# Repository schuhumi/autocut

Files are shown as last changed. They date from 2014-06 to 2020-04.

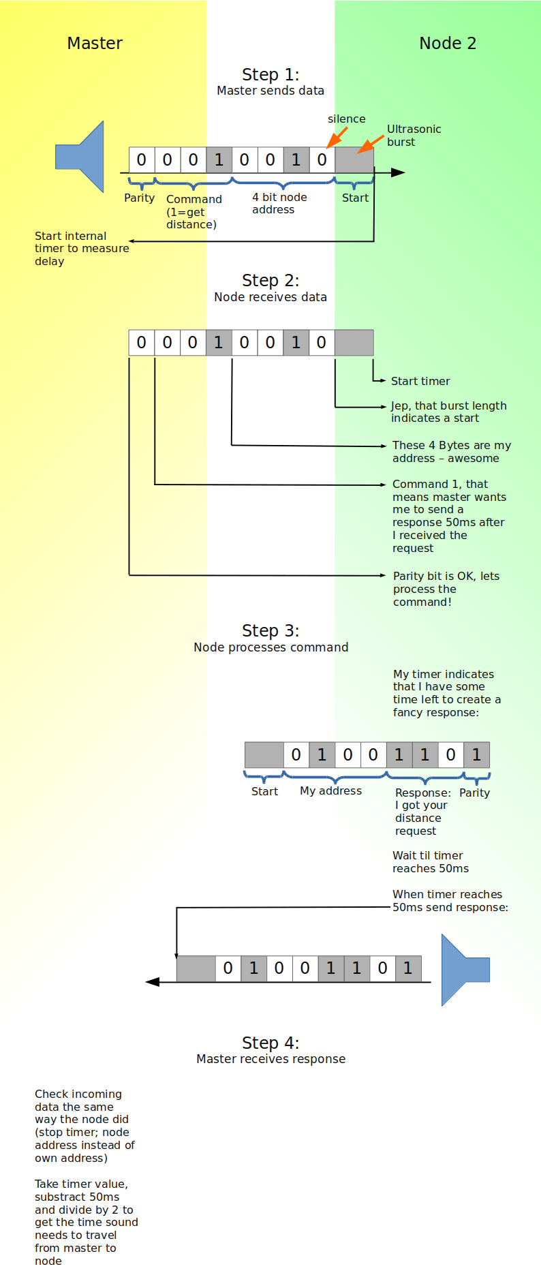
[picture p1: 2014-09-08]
Sketchboard/Ultrasonic Positioning System/Positioning System - the process.png

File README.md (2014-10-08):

autoCut
=======

autoCut is an automatic lawn mower robot. It features:
 - Four weel drive with kink steering
 - Motorized mowing height leveling
 - Two 85 watt mowing motors, each equipped with two very sharp blades, able to snap back on hard obstacles
 - On the fly interchangeable LiPo-battery with voltage monitoring
 - Wifi network connection for web interface which includes gamepad remote control
 - Raspberry Pi as its main computer and head of the microcontroller i2c-network

progress
========

What it can do already:
-----------------------
 - [drive system] works pretty much brilliant
 - [power supply] Measures individual cell voltages and rings an audible alarm in case of undervoltage or improper connected battery. Handles battery changes without losing power for the control system
 - [main module] Raspberry works quite well with ArchLinux ARM and provides a webinterface on the network. Will be replaced by Cubieboard 2 since RasPi has hardware I2C issues
 - [mowing module] Runs the mowing motors with a reasonably decent rpm regulation algorithm. Electrical mowing height adjustment through web interface is implemented.

What it can't do yet:
---------------------
 - [power supply] Measure the current as well as the total battery voltage
 - [general] No environmental sensoring for automatic movement yet, so manual control is needed

Things to improve:
------------------
 - [power supply] design a proper pcb (its on a prototyping board so far)
 - [mowing module] Change FETs for ones with lower heat dissipation and enhance the rpm regulation algorithm

Preserved for the future:
-------------------------
 - Build an automatic battery changing and charging station

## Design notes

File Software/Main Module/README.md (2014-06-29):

The software on the main module is separated into two parts.

Webserver
---------
The webserver hosts a html file and some javascript. This builds up the webinteface. Nginx is recommended as webserver, since its more lightweight than apache - which is a good thing on a weak emdedded platform.

Commandserver
-------------
This is a websocket-server written in Python3. It receives commands, processes them and sends information back. The webinterface uses the commandserver to control the robot.

RobotLibrary is a pile of functions for communicating with other modules (drive, mow, powersupply...) via I2C easily. The Commandserver uses them to process the commands.

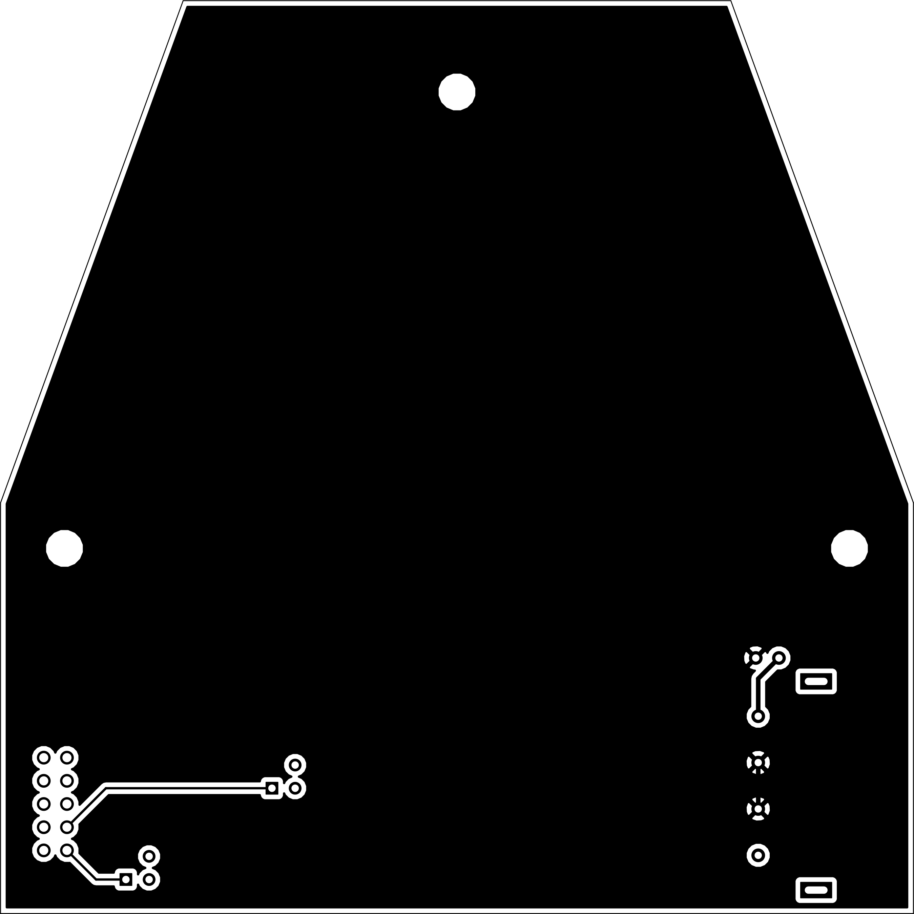
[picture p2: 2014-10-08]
Electronics/Main Module/MainModule-B_Cu.png

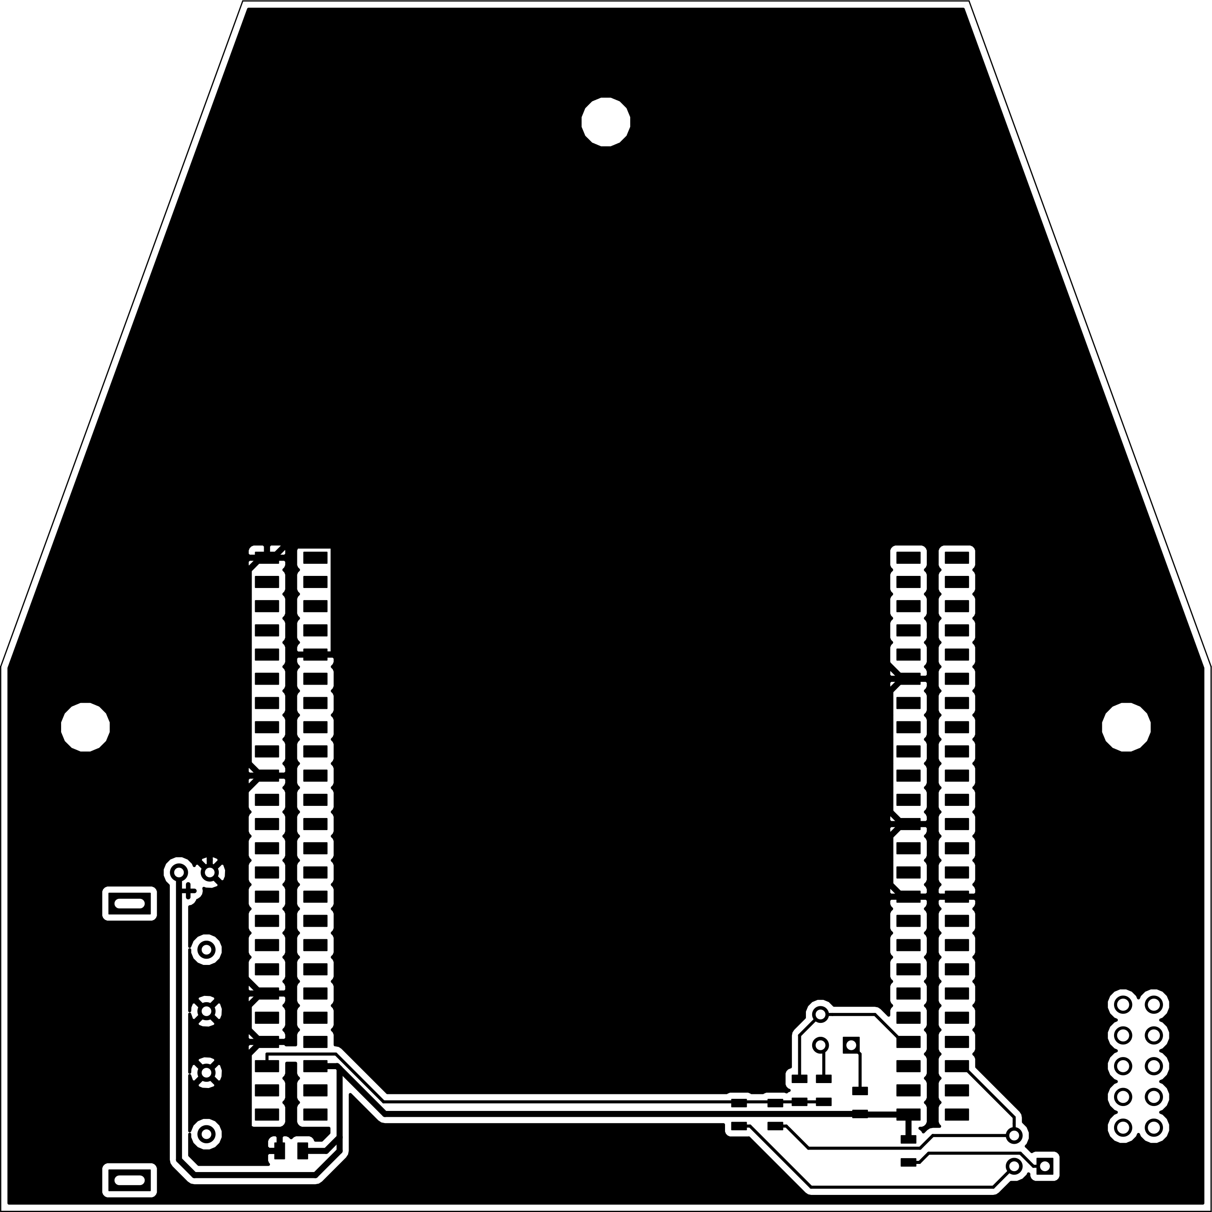
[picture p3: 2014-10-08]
Electronics/Main Module/MainModule-F_Cu.png

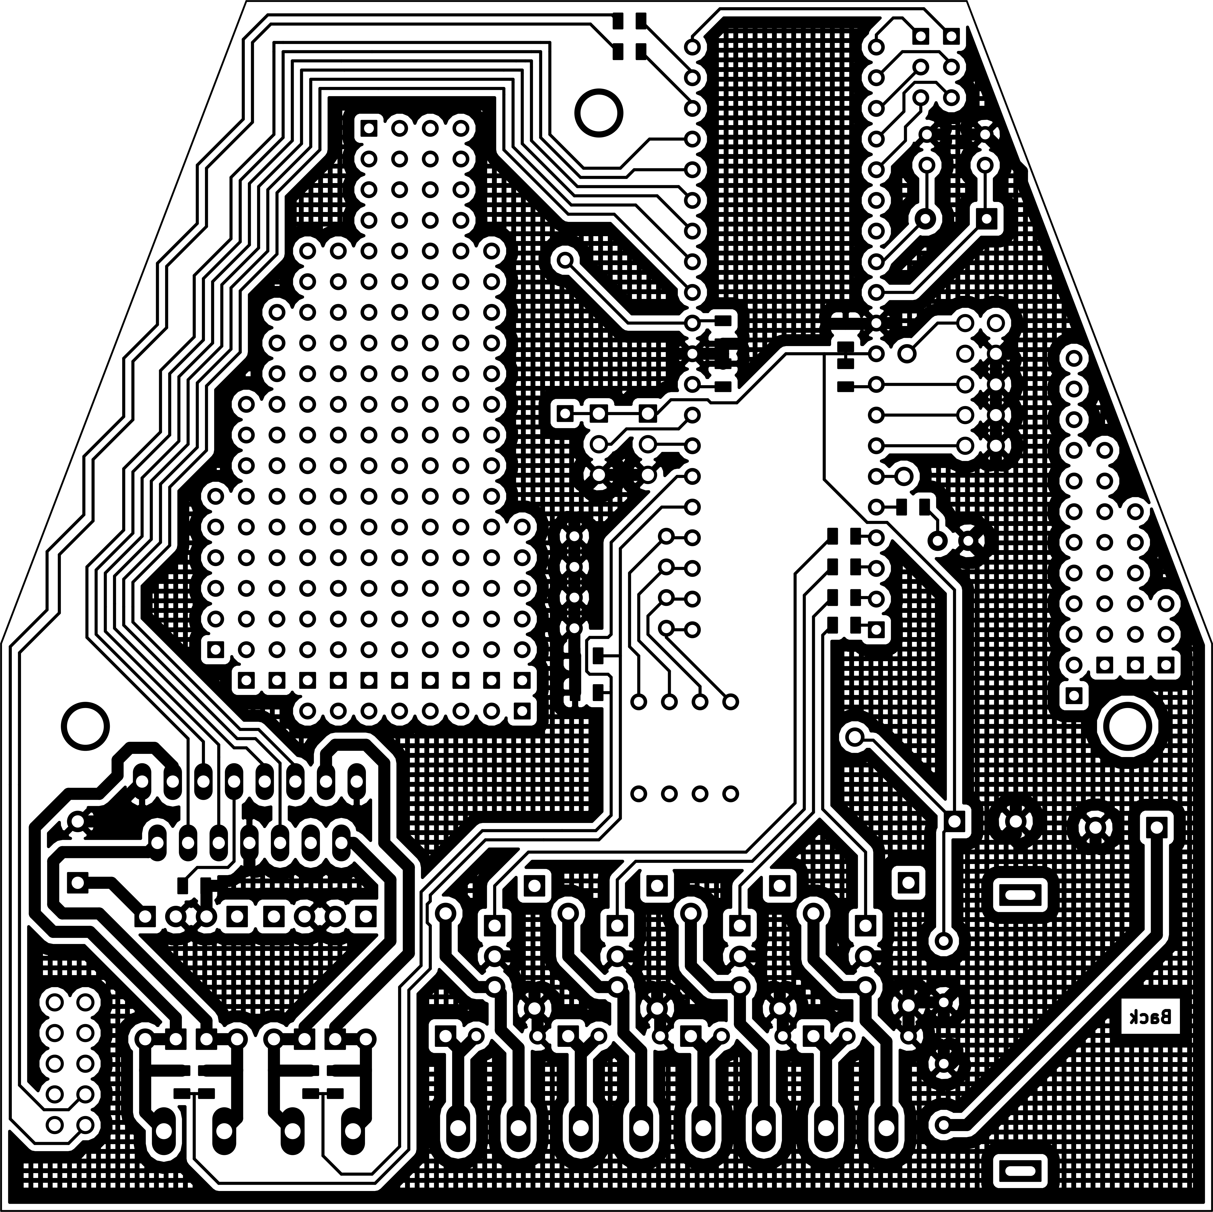
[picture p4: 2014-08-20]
Electronics/Mowing Module/plot/maehwerktreiber-B_Cu_grid.png

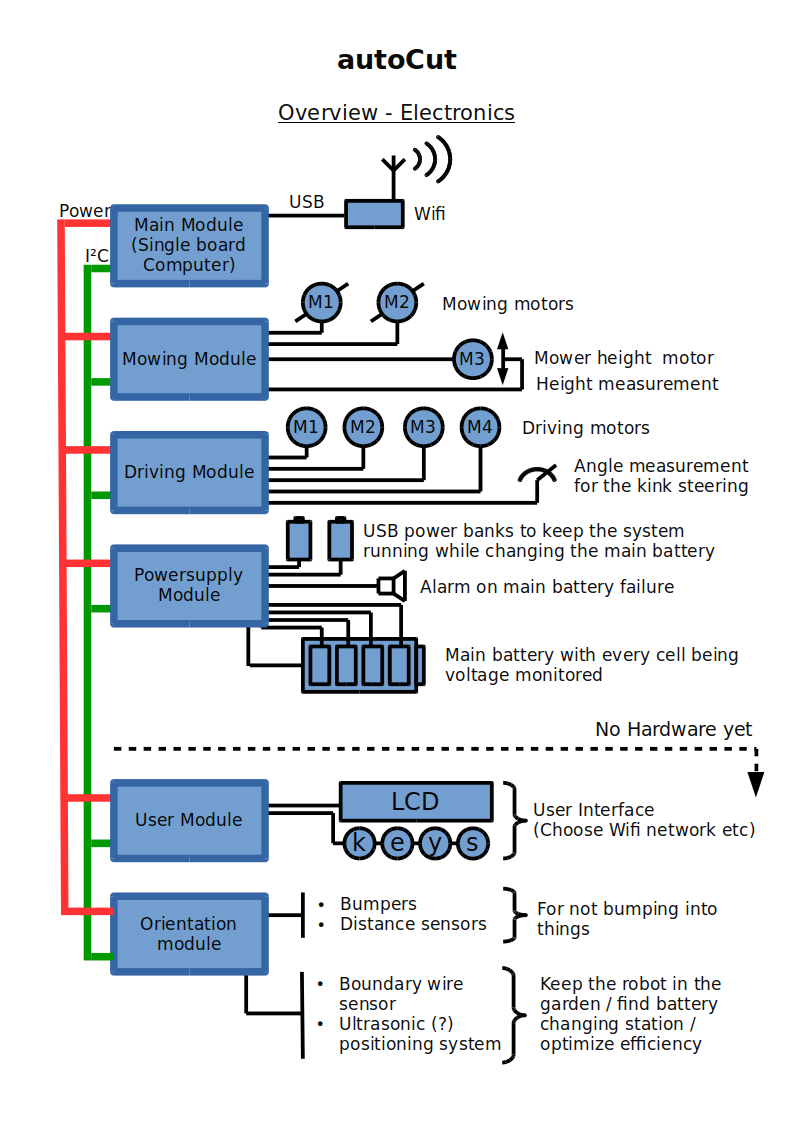
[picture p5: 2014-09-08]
Documentation/Visualisation/Overview - Electronics/Overview - Electronics.png

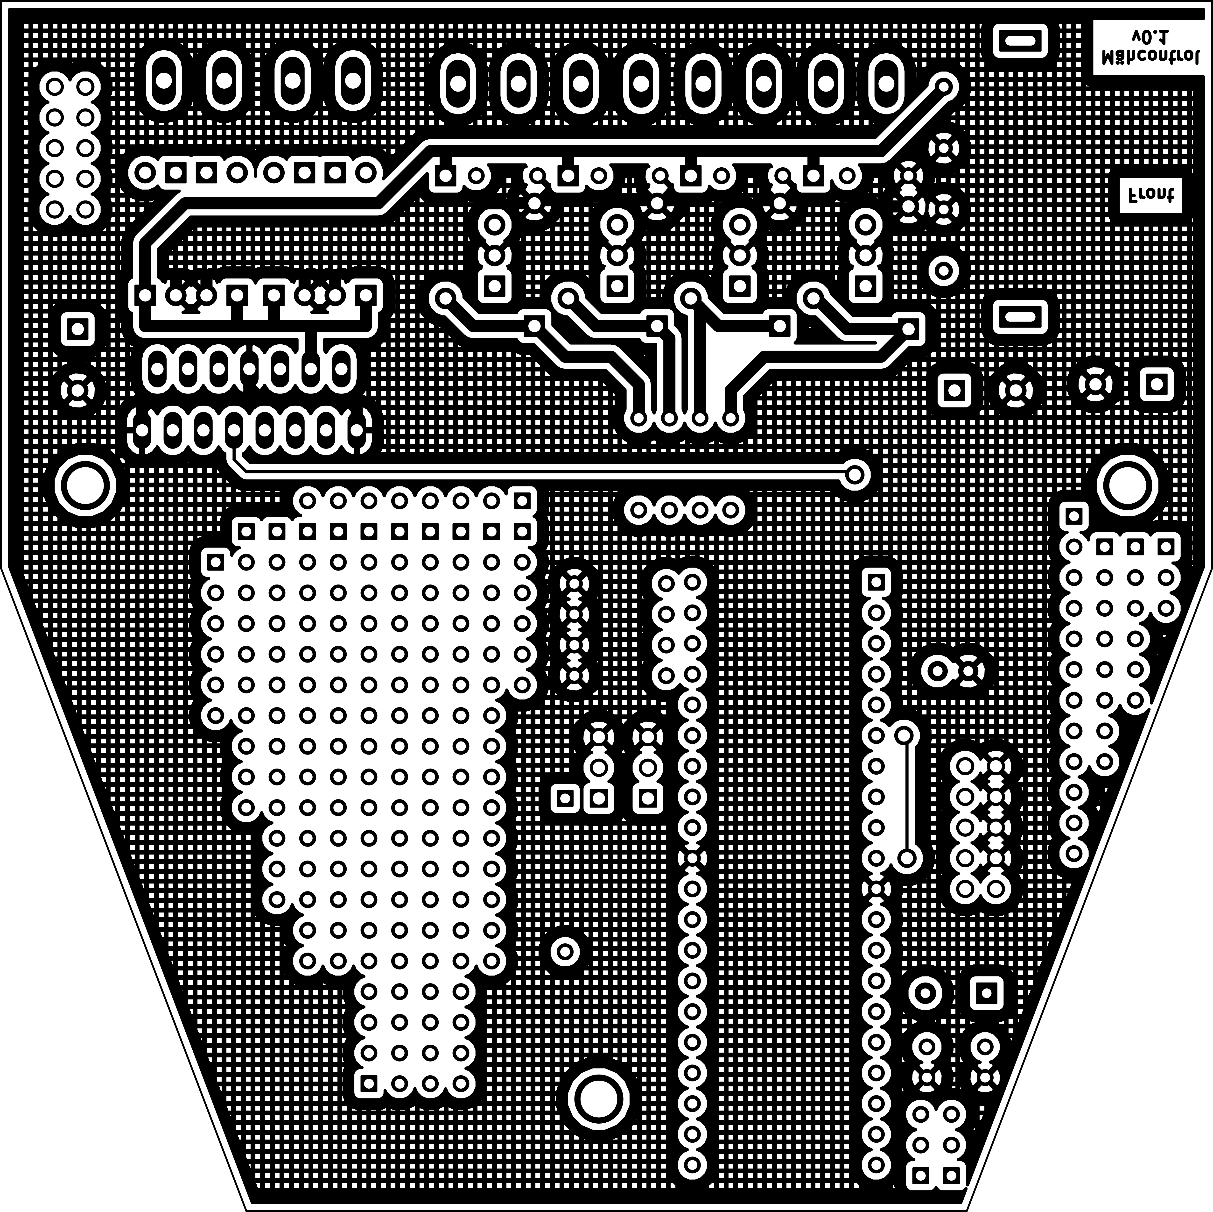
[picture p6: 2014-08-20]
Electronics/Mowing Module/plot/maehwerktreiber-F_Cu_grid.png

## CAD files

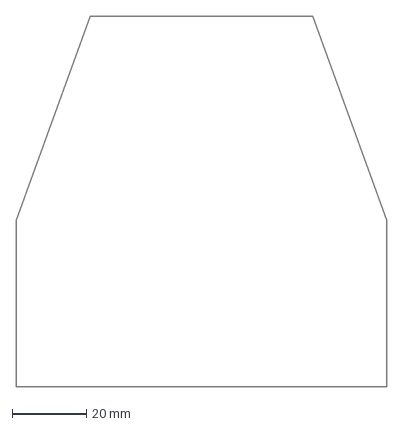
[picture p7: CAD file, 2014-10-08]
Electronics/Main Module/EdgeCuts.dxf
100.0 x 100.0 mm

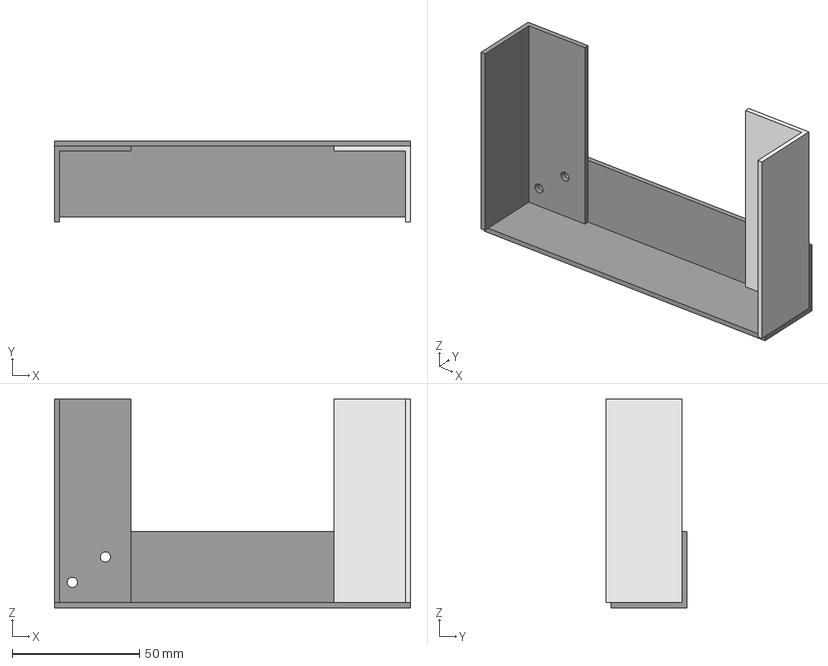
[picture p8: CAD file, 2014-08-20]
Mechanics/Chassis/Chassis.fcstd
140.0 x 32.0 x 82.0 mm

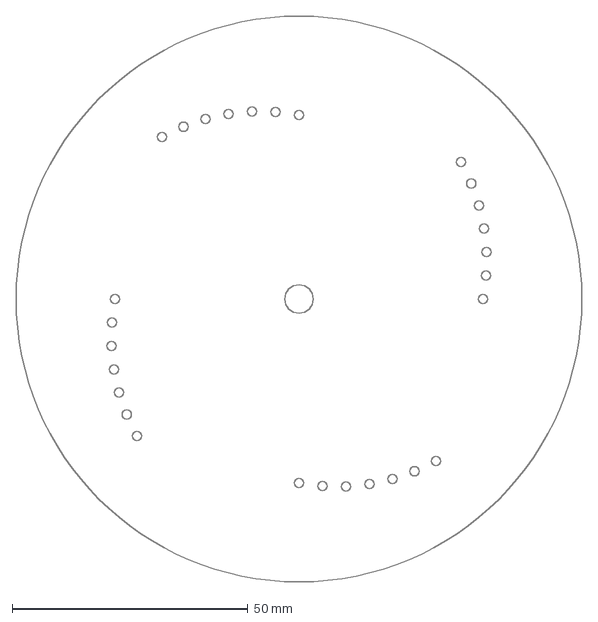
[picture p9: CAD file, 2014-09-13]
Mechanics/Mowing deck/mowing_plates.dxf
120.0 x 120.0 mm

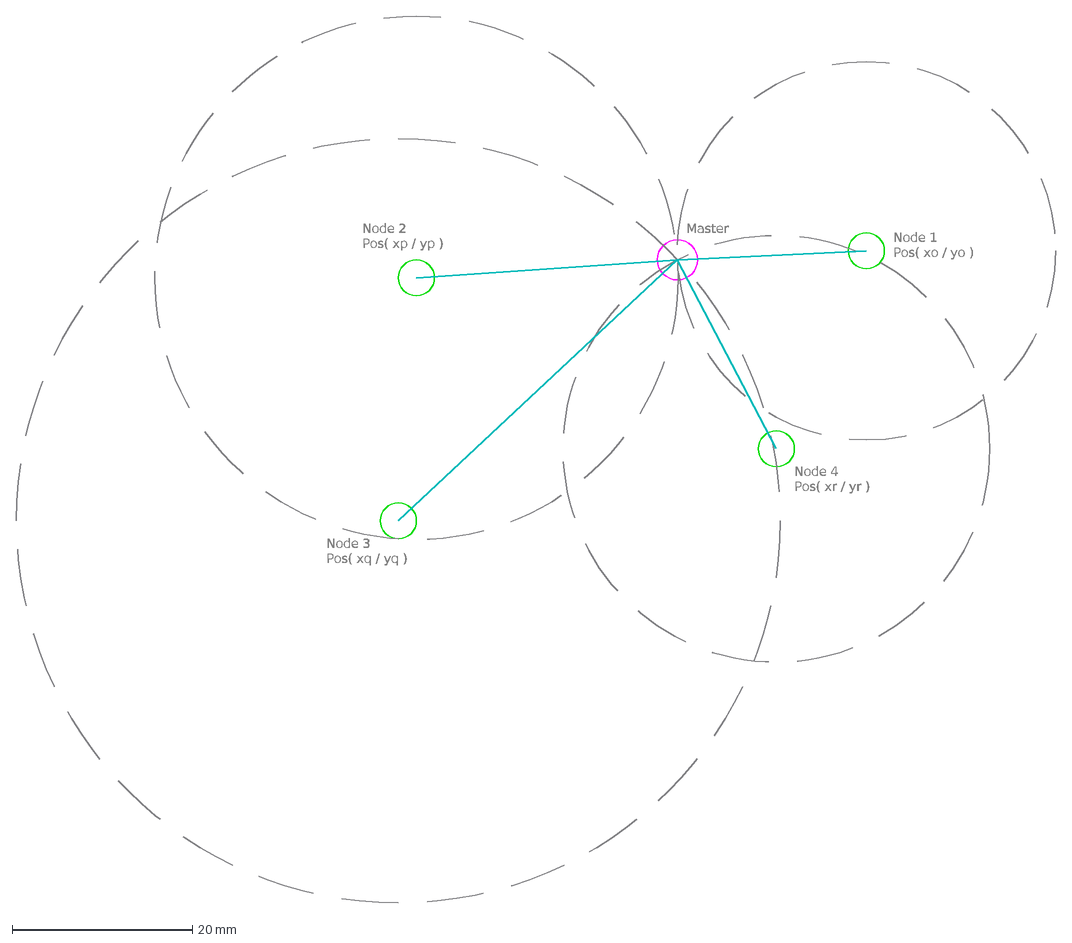
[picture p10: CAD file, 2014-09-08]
Sketchboard/Ultrasonic Positioning System/Positioning System.dxf
Node 2 Pos( xp / yp )
Node 1 Pos( xo / yo )
Node 3 Pos( xq / yq )
Node 4 Pos( xr / yr )
Master

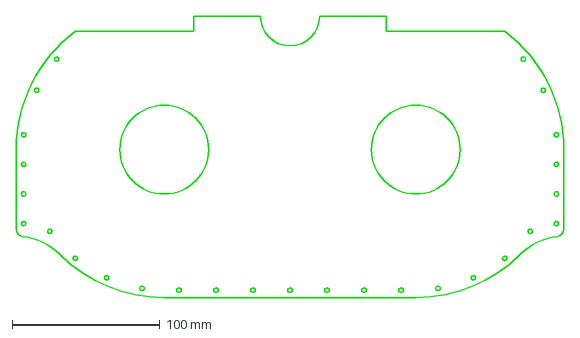
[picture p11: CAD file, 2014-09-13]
Mechanics/Mowing deck/mowing_system_abdeckung.dxf
370.0 x 190.0 mm

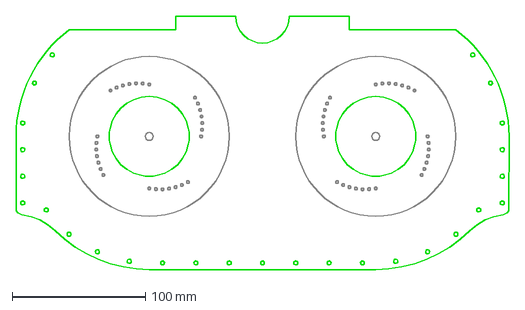
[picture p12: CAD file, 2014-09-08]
Mechanics/Mowing deck/mowing_system.dxf
370.0 x 190.0 mm

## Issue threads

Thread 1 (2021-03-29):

RE: I Just Saw this Idea/Seth

silver2row, 2021-03-29:
Hello,

https://www.open-electronics.org/a-robotic-lawn-mowers-powered-by-solar-energy-with-an-arduino-heart/

I know the above link has an arduino but there is a control circuit in that link further down the page for burying cables to handle runoff of the vehicle/autocut.

I thought this could help.

Seth

P.S. Anyway, I wish you luck w/ your endeavors. I started to follow this page and forked it too! So, I will attempt to perform this idea w/ my Beagleboard.org boards in the future. 3.3v logic is the idea w/ their boards...I will try it out!

Closed 2021-04-12.

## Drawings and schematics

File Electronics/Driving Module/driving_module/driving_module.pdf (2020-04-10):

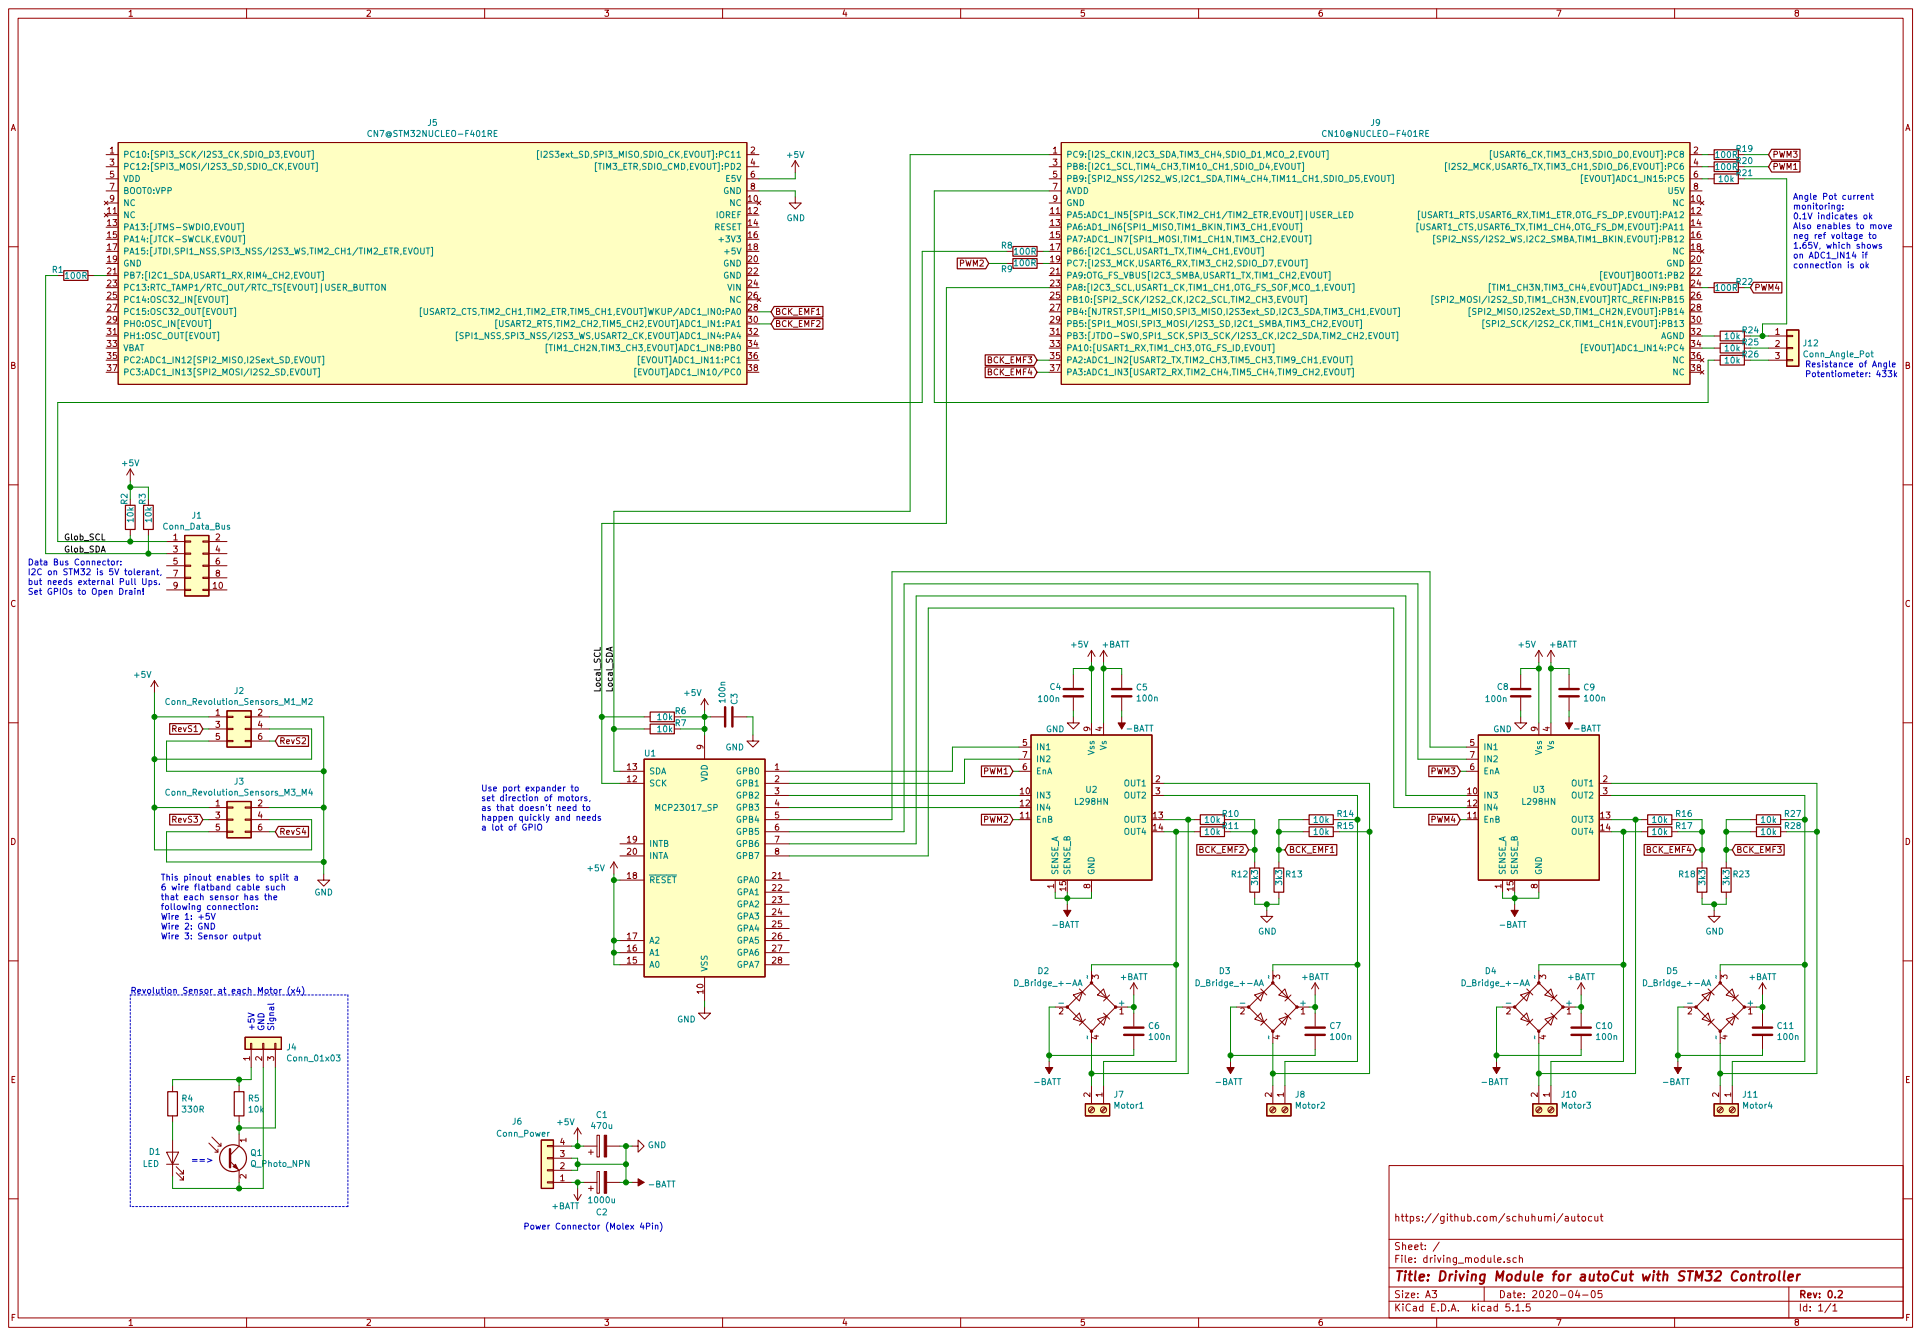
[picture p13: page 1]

Angle Pot current
monitoring: 0.1V indicates ok Also enables to move

neg ref voltage to
1.65V, which shows on ADC1_IN14 if connection is ok

Data Bus Connector:
I2C on STM32 is 5V tolerant, but needs external Pull Ups.

Set GPIOs to Open Drain!

following connection: Wire 1: +5V Wire 2: GND Wire 3: Sensor output +5V GND Signal ==>

Use port expander to
set direction of motors, as that doesn't need to

happen quickly and needs a lot of GPIO

This pinout enables to split a 6 wire flatband cable such

that each sensor has the

Revolution Sensor at each Motor (x4)

Id: 1/1 Title: Driving Module for autoCut with STM32 Controller

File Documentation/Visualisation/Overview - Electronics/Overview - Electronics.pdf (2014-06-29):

## autoCut

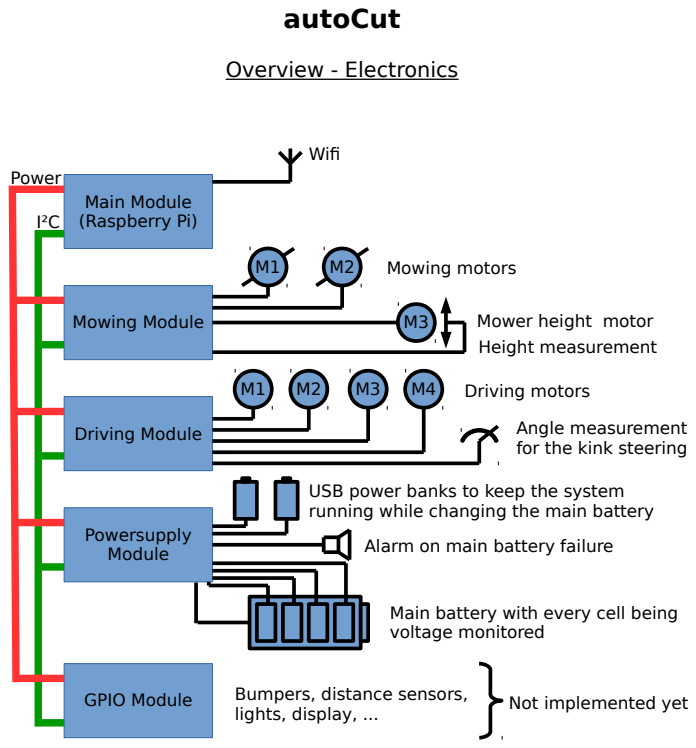
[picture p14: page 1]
Main Module (Raspberry Pi); Driving Module; Mowing Module; Powersupply Module; I²C; Power; Wif; Mowing motors; Mower height motor; Height measurement; Driving motors; Overview - Electronics; GPIO Module; Bumpers, distance sensors,; lights, display, ...; Not implemented yet

Angle measurement
for the kink steering

USB power banks to keep the system
running while changing the main battery
Alarm on main battery failure

Main battery with every cell being
voltage monitored

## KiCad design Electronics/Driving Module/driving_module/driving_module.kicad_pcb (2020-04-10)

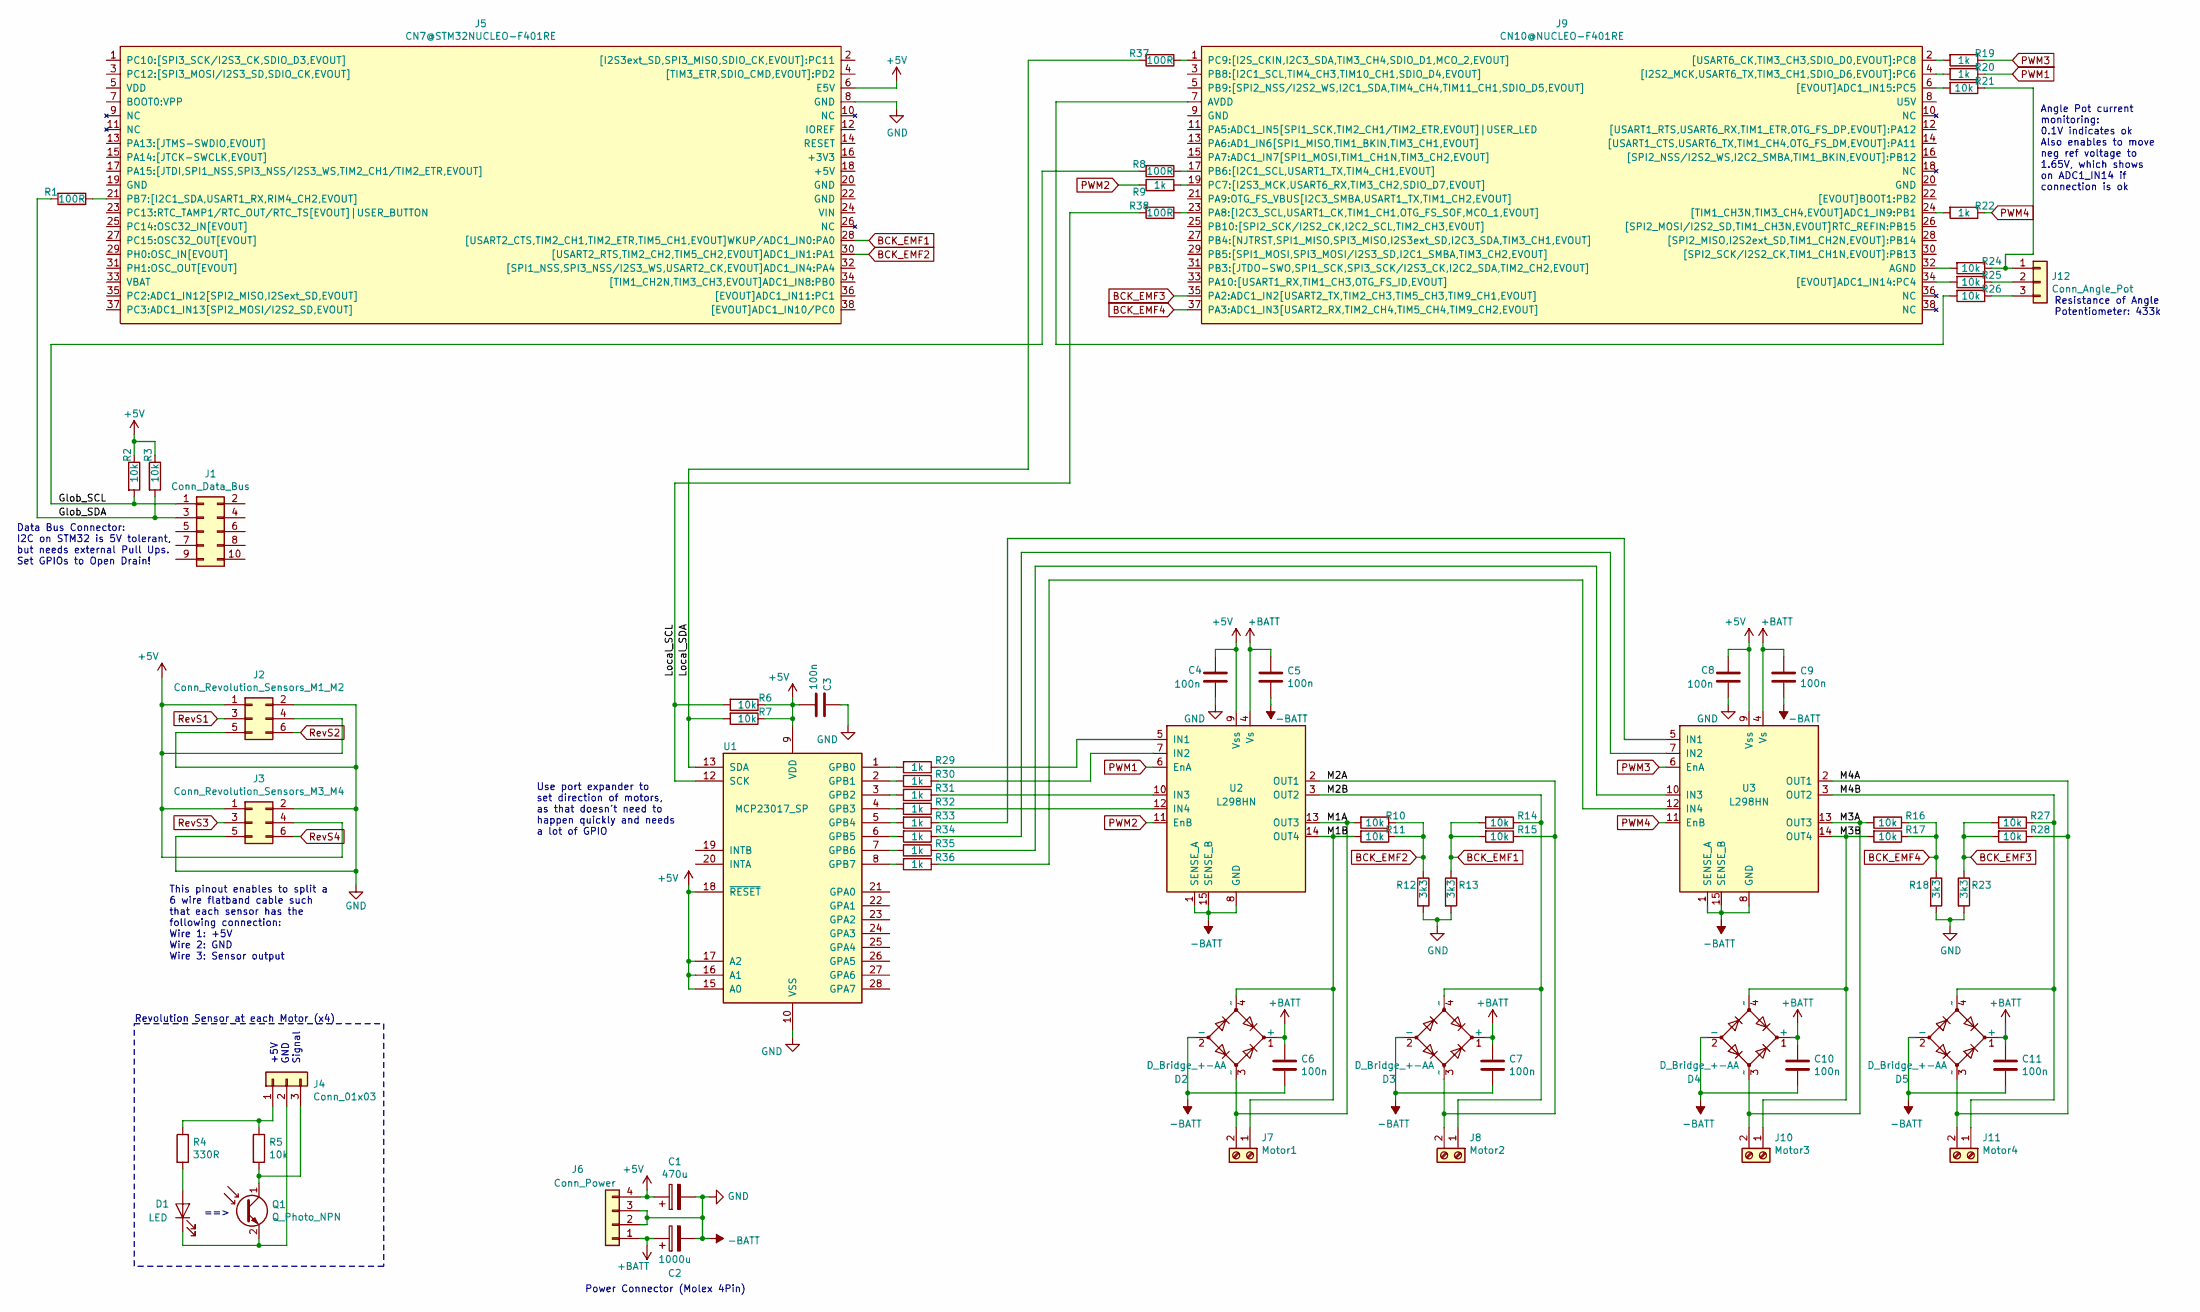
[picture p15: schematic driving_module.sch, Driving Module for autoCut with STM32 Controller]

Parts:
C1: 470u; CP_Radial_D8.0mm_P5.00mm
C2: 1000u; CP_Radial_D12.5mm_P5.00mm
C3, C4, C5, C6, C7, C8, C9, C10, C11: 100n; C_0805_2012Metric
D1: LED; LED_D3.0mm_Clear
D2, D3, D4, D5: D_Bridge_+-AA; Diode_Bridge_Diotec_SO-DIL-Slim
J1: Conn_Data_Bus; IDC-Header_2x05_P2.54mm_Vertical
J2: Conn_Revolution_Sensors_M1_M2; IDC-Header_2x03_P2.54mm_Vertical
J3: Conn_Revolution_Sensors_M3_M4; IDC-Header_2x03_P2.54mm_Vertical
J4: Conn_01x03; PinHeader_1x03_P2.54mm_Vertical
J5: CN7@STM32NUCLEO-F401RE; PinSocket_2x19_P2.54mm_Vertical
J6: Conn_Power; xess-MOLEX-8981-04P
J7: Motor1; TerminalBlock_bornier-2_P5.08mm
J8: Motor2; TerminalBlock_bornier-2_P5.08mm
J9: CN10@NUCLEO-F401RE; PinSocket_2x19_P2.54mm_Vertical
J10: Motor3; TerminalBlock_bornier-2_P5.08mm
J11: Motor4; TerminalBlock_bornier-2_P5.08mm
J12: Conn_Angle_Pot; PinHeader_1x03_P2.54mm_Vertical
Q1: Q_Photo_NPN; LED_D3.0mm_Clear
R1, R8, R37, R38: 100R; R_0805_2012Metric
R2, R3, R5, R6, R7, R10, R11, R14, R15, R16, R17, R21, R24, R25, R26, R27, R28: 10k; R_0805_2012Metric
R4: 330R; R_0805_2012Metric
R9, R19, R20, R22, R29, R30, R31, R32, R33, R34, R35, R36: 1k; R_0805_2012Metric
R12, R13, R18, R23: 3k3; R_Axial_DIN0207_L6.3mm_D2.5mm_P7.62mm_Horizontal
U1: MCP23017_SP; DIP-28_W7.62mm
U2, U3: L298HN; TO-220-15_P2.54x2.54mm_StaggerOdd_Lead4.58mm_Vertical_bent_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

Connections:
+5V: C1.1, C3.2, C4.1, C8.1, J2.1, J2.4, J3.1, J3.4, J5.6 (E5V), J6.4, R2.1, R3.1, R6.1, R7.1, U1.9 (VDD), U1.15 (A0), U1.16 (A1), U1.17 (A2), U1.18 (~RESET~), U2.9 (Vss), U3.9 (Vss)
+BATT: C2.1, C5.1, C6.1, C7.1, C9.1, C10.1, C11.1, D2.1 (+), D3.1 (+), D4.1 (+), D5.1 (+), J6.1, U2.4 (Vs), U3.4 (Vs)
-BATT: C1.2, C2.2, C3.1, C4.2, C5.2, C6.2, C7.2, C8.2, C9.2, C10.2, C11.2, D2.2 (-), D3.2 (-), D4.2 (-), D5.2 (-), J2.2, J2.5, J3.2, J3.5, J5.8 (GND), J6.2, J6.3, R12.2, R13.2, R18.2, R23.2, U1.10 (VSS), U2.1 (SENSE_A), U2.8 (GND), U2.15 (SENSE_B), U3.1 (SENSE_A), U3.8 (GND), U3.15 (SENSE_B)
/Glob_SCL: J1.1, R2.2, R8.2
/Glob_SDA: J1.3, R1.2, R3.2
/Local_SCL: R6.2, R38.2, U1.12 (SCK)
/Local_SDA: R7.2, R37.2, U1.13 (SDA)
/M1A: D2.3 (~~), J7.2, R10.2, U2.13 (OUT3)
/M1B: D2.4 (~~), J7.1, R11.2, U2.14 (OUT4)
/M2A: D3.3 (~~), J8.2, R15.1, U2.2 (OUT1)
/M2B: D3.4 (~~), J8.1, R14.1, U2.3 (OUT2)
/M3A: D4.3 (~~), J10.2, R16.2, U3.13 (OUT3)
/M3B: D4.4 (~~), J10.1, R17.2, U3.14 (OUT4)
/M4A: D5.3 (~~), J11.2, R28.1, U3.2 (OUT1)
/M4B: D5.4 (~~), J11.1, R27.1, U3.3 (OUT2)
BCK_EMF1: J5.28 ([USART2_CTS,TIM2_CH1,TIM2_ETR,TIM5_CH1,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), R13.1, R14.2, R15.2
BCK_EMF2: J5.30 ([USART2_RTS,TIM2_CH2,TIM5_CH2,EVOUT]ADC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), R10.1, R11.1, R12.1
BCK_EMF3: J9.35 (PA2:ADC1_IN2[USART2_TX,TIM2_CH3,TIM5_CH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), R23.1, R27.2, R28.2
BCK_EMF4: J9.37 (PA3:ADC1_IN3[USART2_RX,TIM2_CH4,TIM5_CH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), R16.1, R17.1, R18.1
unnamed: D1.1 (K), J4.2, Q1.2 (E)
unnamed: D1.2 (A), R4.2
unnamed: J4.1, R4.1, R5.1
unnamed: J4.3, Q1.1 (C), R5.2
unnamed: J5.21 (PB7:[I2C1_SDA,USART1_RX,RIM4_CH2,EVOUT]), R1.1
unnamed: J9.1 (PC9:[I2S_CKIN,I2C3_SDA,TIM3_CH4,SDIO_D1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), R37.1
unnamed: J9.2 ([USART6_CK,TIM3_CH3,SDIO_D0,EVOUT]:PC8), R19.2
unnamed: J9.4 ([I2S2_MCK,USART6_TX,TIM3_CH1,SDIO_D6,EV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), R20.2
unnamed: J9.6 ([EVOUT]ADC1_IN15:PC5), R21.2
unnamed: J9.7 (AVDD), R26.2
unnamed: J9.17 (PB6:[I2C1_SCL,USART1_TX,TIM4_CH1,EVOUT]), R8.1
unnamed: J9.19 (PC7:[I2S3_MCK,USART6_RX,TIM3_CH2,SDIO_D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), R9.2
unnamed: J9.23 (PA8:[I2C3_SCL,USART1_CK,TIM1_CH1,OTG_FS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), R38.1
unnamed: J9.24 ([TIM1_CH3N,TIM3_CH4,EVOUT]ADC1_IN9:PB1), R22.2
unnamed: J9.32 (AGND), R24.2
unnamed: J9.34 ([EVOUT]ADC1_IN14:PC4), R25.2
unnamed: J12.1, R21.1, R24.1
unnamed: J12.2, R25.1
unnamed: J12.3, R26.1
unnamed: R29.1, U2.5 (IN1)
unnamed: R29.2, U1.1 (GPB0)
unnamed: R30.1, U2.7 (IN2)
unnamed: R30.2, U1.2 (GPB1)
unnamed: R31.1, U2.10 (IN3)
unnamed: R31.2, U1.3 (GPB2)
unnamed: R32.1, U2.12 (IN4)
unnamed: R32.2, U1.4 (GPB3)
unnamed: R33.1, U3.5 (IN1)
unnamed: R33.2, U1.5 (GPB4)
unnamed: R34.1, U3.7 (IN2)
unnamed: R34.2, U1.6 (GPB5)
unnamed: R35.1, U3.10 (IN3)
unnamed: R35.2, U1.7 (GPB6)
unnamed: R36.1, U3.12 (IN4)
unnamed: R36.2, U1.8 (GPB7)
PWM1: R20.1, U2.6 (EnA)
PWM2: R9.1, U2.11 (EnB)
PWM3: R19.1, U3.6 (EnA)
PWM4: R22.1, U3.11 (EnB)
RevS1: J2.3
RevS2: J2.6
RevS3: J3.3
RevS4: J3.6

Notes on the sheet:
Resistance of Angle Potentiometer: 433k
Angle Pot current monitoring: 0.1V indicates ok Also enables to move neg ref voltage to 1.65V, which shows on ADC1_IN14 if connection is ok
Data Bus Connector: I2C on STM32 is 5V tolerant, but needs external Pull Ups. Set GPIOs to Open Drain!
Use port expander to set direction of motors, as that doesn't need to happen quickly and needs a lot of GPIO
This pinout enables to split a 6 wire flatband cable such that each sensor has the following connection: Wire 1: +5V Wire 2: GND Wire 3: Sensor output
+5V GND Signal
==>
Revolution Sensor at each Motor (x4)
Power Connector (Molex 4Pin)

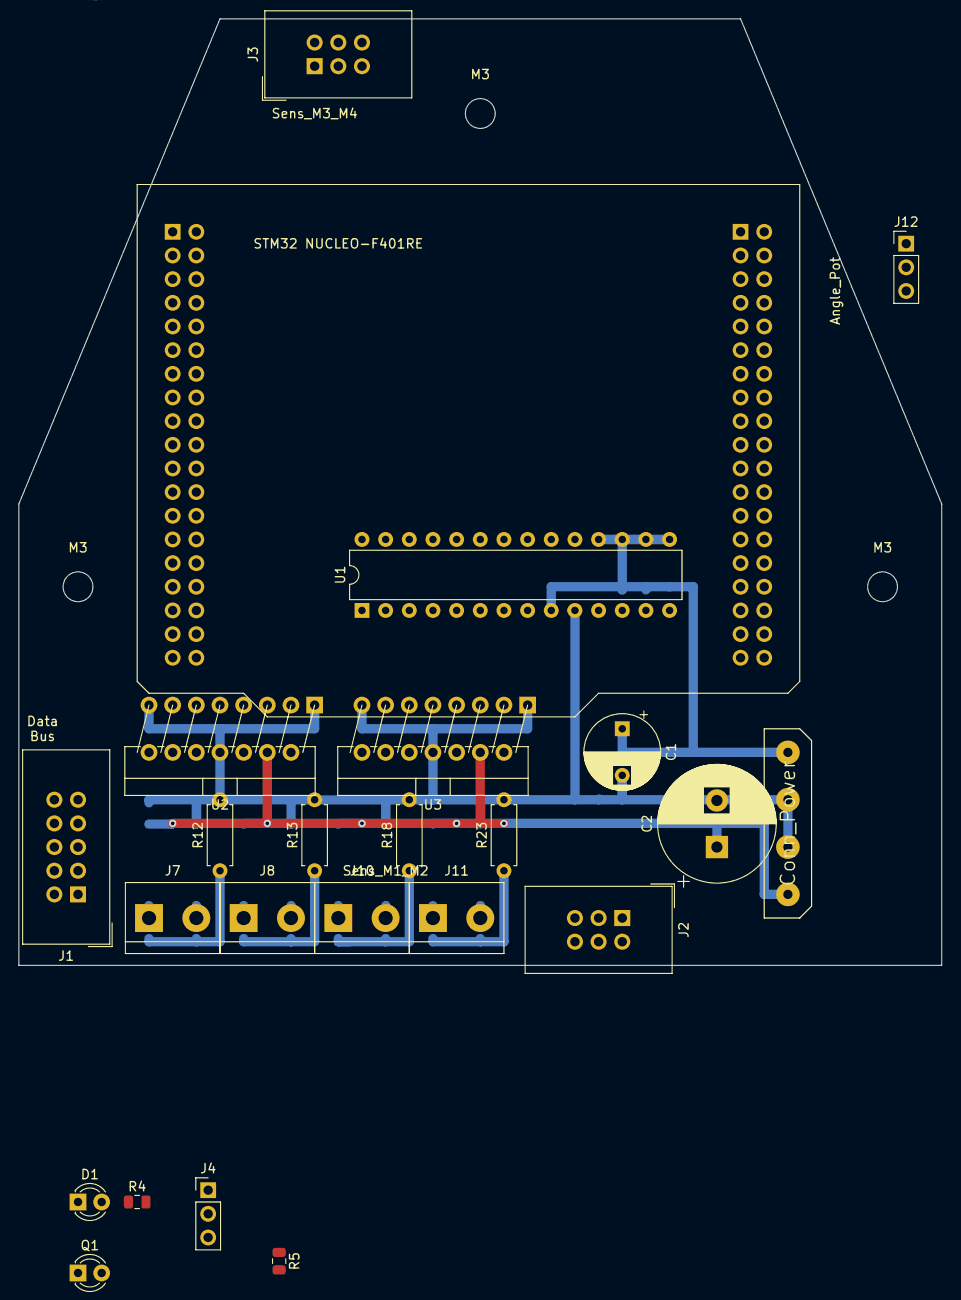
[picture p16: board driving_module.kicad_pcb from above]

Board: 4 copper layers, 99.1 x 101.6 mm, 73 parts (0 on the bottom side), 58 nets.

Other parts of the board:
M3, M3#2, M3#3: MountingHole_3.2mm_M3

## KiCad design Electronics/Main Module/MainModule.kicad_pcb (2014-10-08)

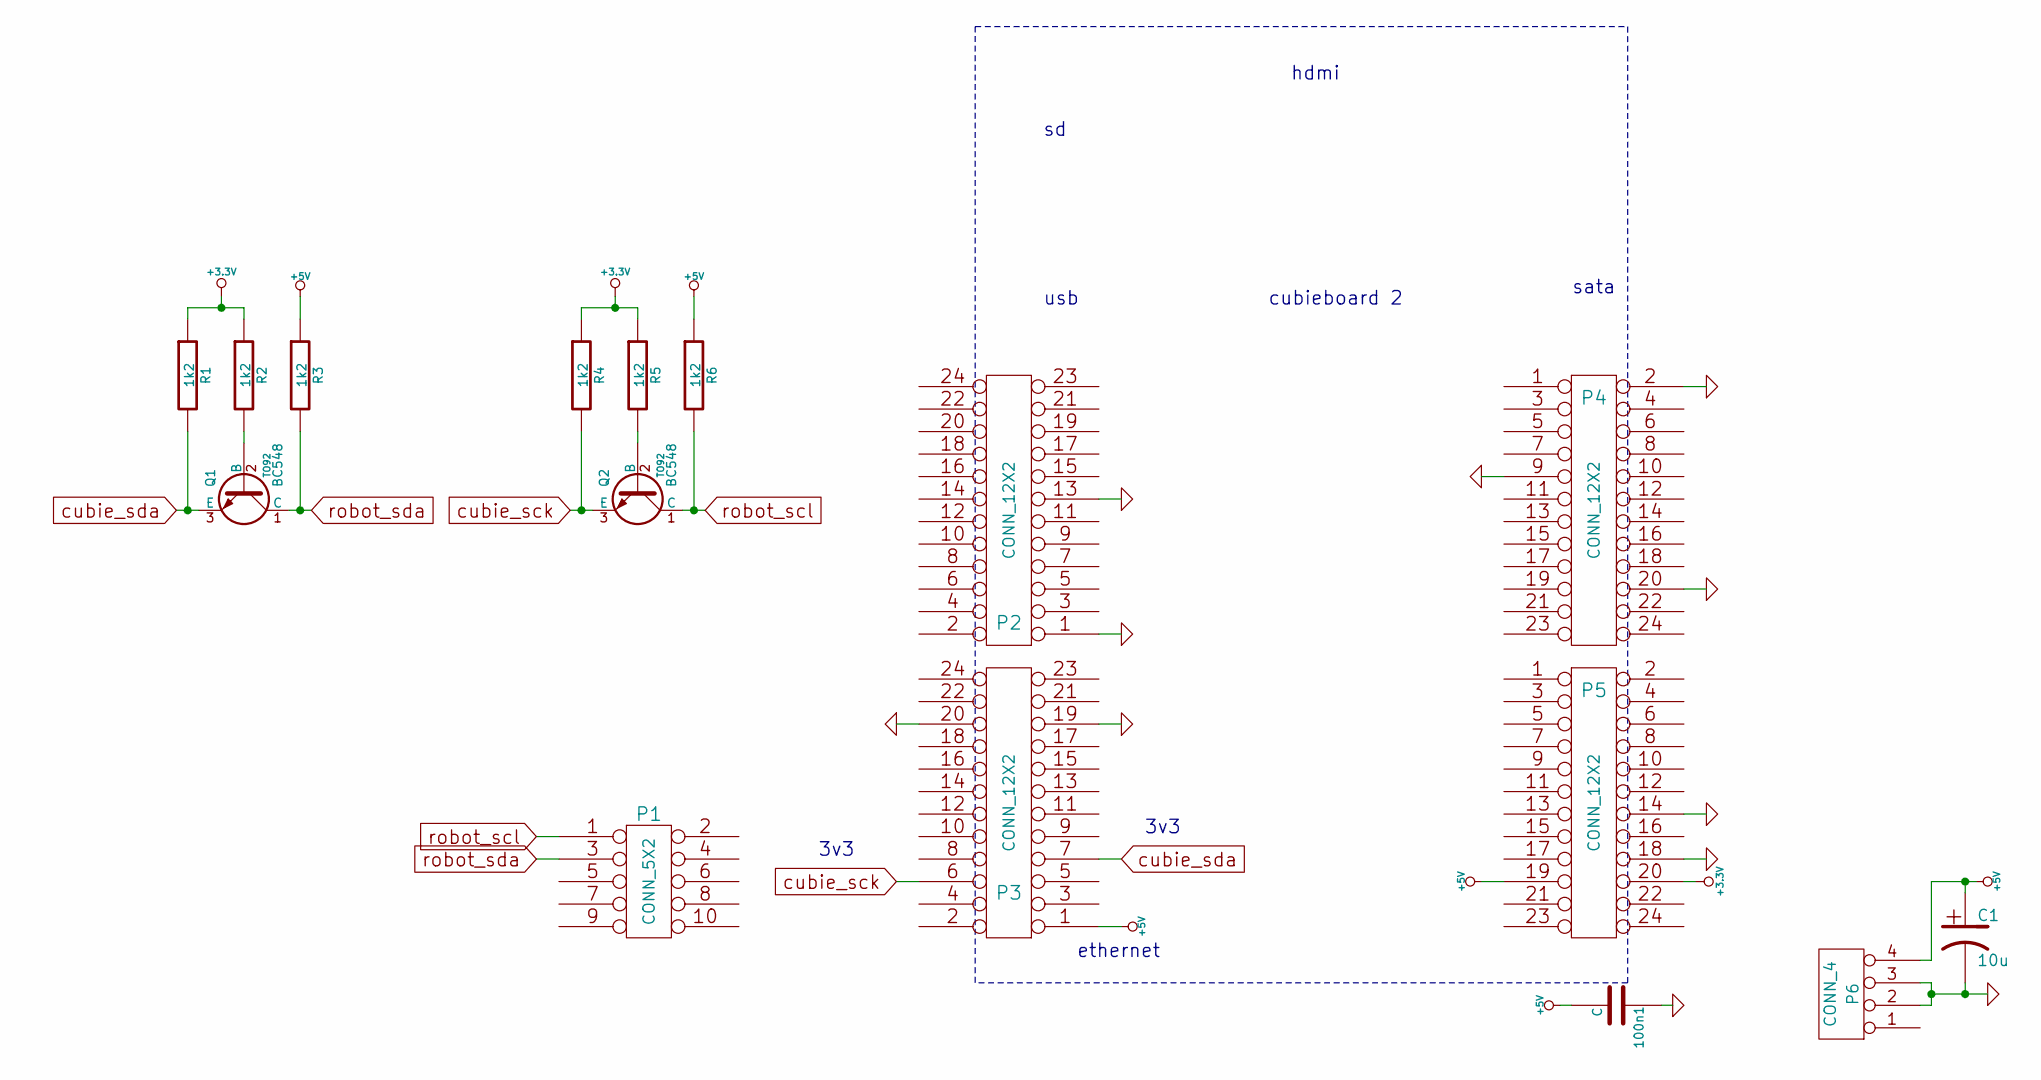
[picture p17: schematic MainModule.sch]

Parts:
100n1: C; SMD-0805
C1: 10u; Elko_vert_DM5_RM2-5
P1: CONN_5X2; VASCH5x2
P2, P3, P4, P5: CONN_12X2; SMD2mm_Header_12x2
P6: CONN_4; Molex
Q1, Q2: BC548; TO92
R1, R2, R3, R4, R5, R6: 1k2; R_0805

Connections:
+3.3V: P5.20, R1.1, R2.1, R4.1, R5.1
+5V: 100n1.2, C1.1, P3.1, P5.19, P6.4, R3.1, R6.1
GND: 100n1.1, C1.2, P2.1, P2.13, P3.19, P3.20, P4.2, P4.9, P4.20, P5.14, P5.18, P6.2, P6.3
unnamed: Q1.2 (B), R2.2
unnamed: Q2.2 (B), R5.2
cubie_sck: P3.6, Q2.3 (E), R4.2
cubie_sda: P3.7, Q1.3 (E), R1.2
robot_scl: P1.1, Q2.1 (C), R6.2
robot_sda: P1.3, Q1.1 (C), R3.2

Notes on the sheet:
cubieboard 2
sata
ethernet
usb
hdmi
3v3

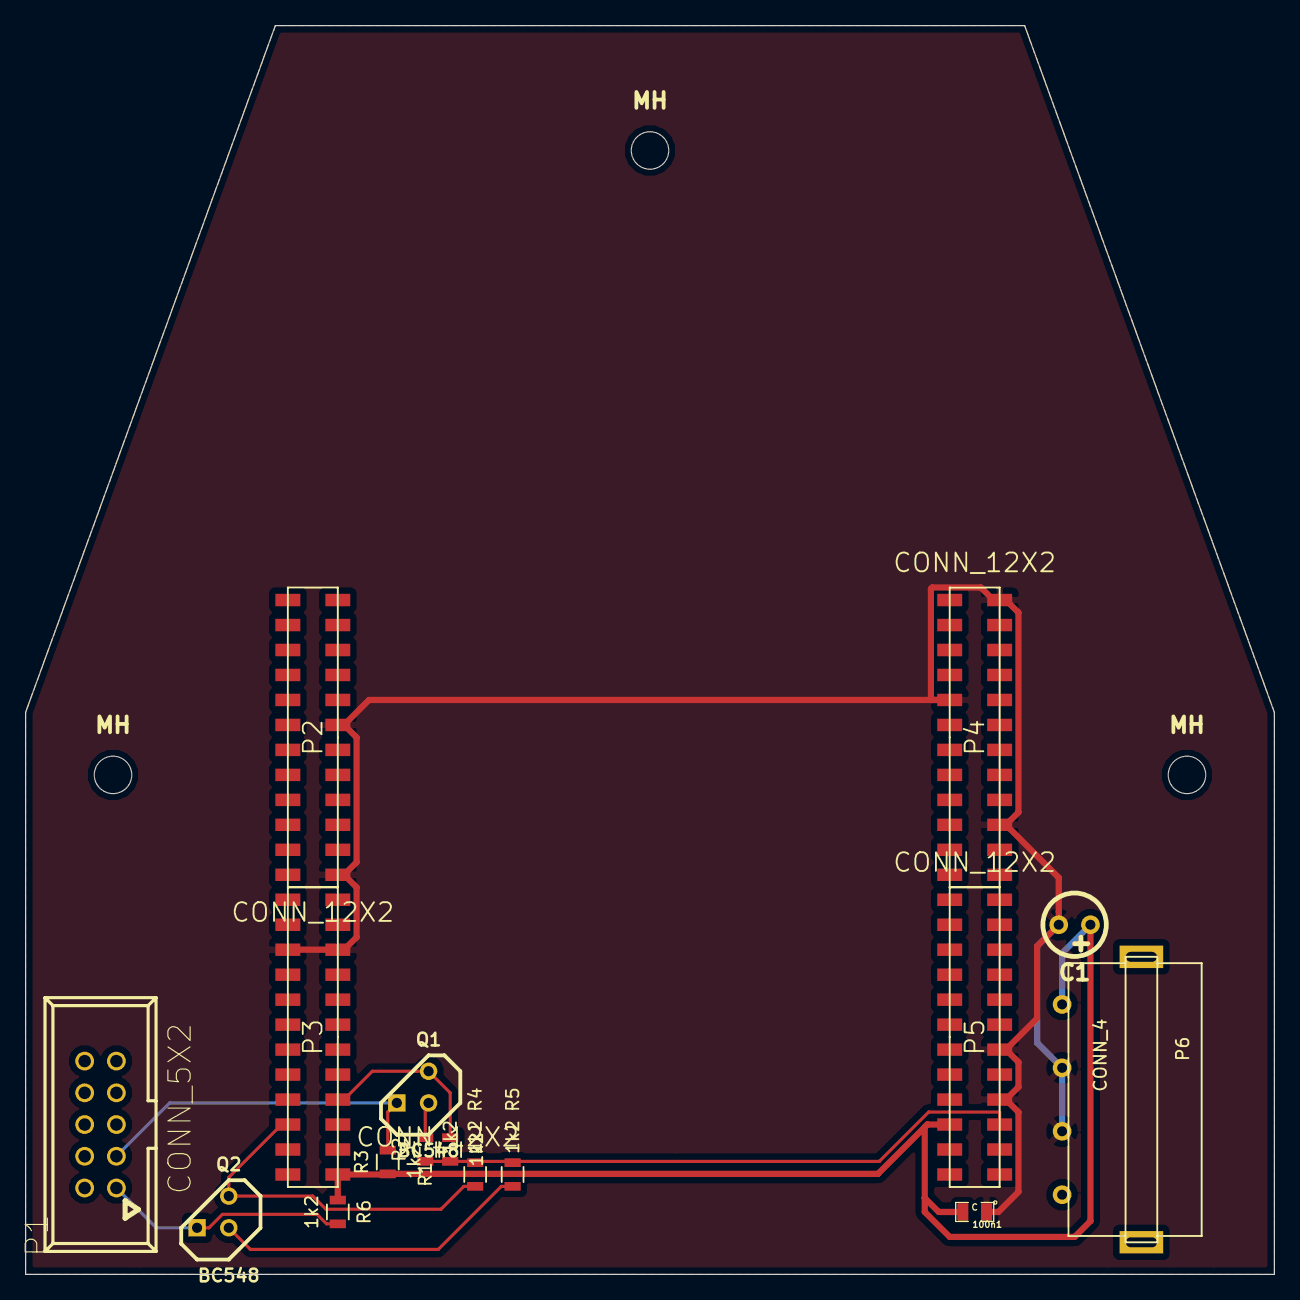
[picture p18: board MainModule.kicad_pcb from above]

Board: 2 copper layers, 100.0 x 100.0 mm, 19 parts (0 on the bottom side), 9 nets.

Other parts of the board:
MH: MountingHole_3mm_RevA_Date21Jun2010; MountingHole_3mm
MH#2, MH#3: MountingHole_3mm_RevA_Date21Jun2010; MountingHole_3mm

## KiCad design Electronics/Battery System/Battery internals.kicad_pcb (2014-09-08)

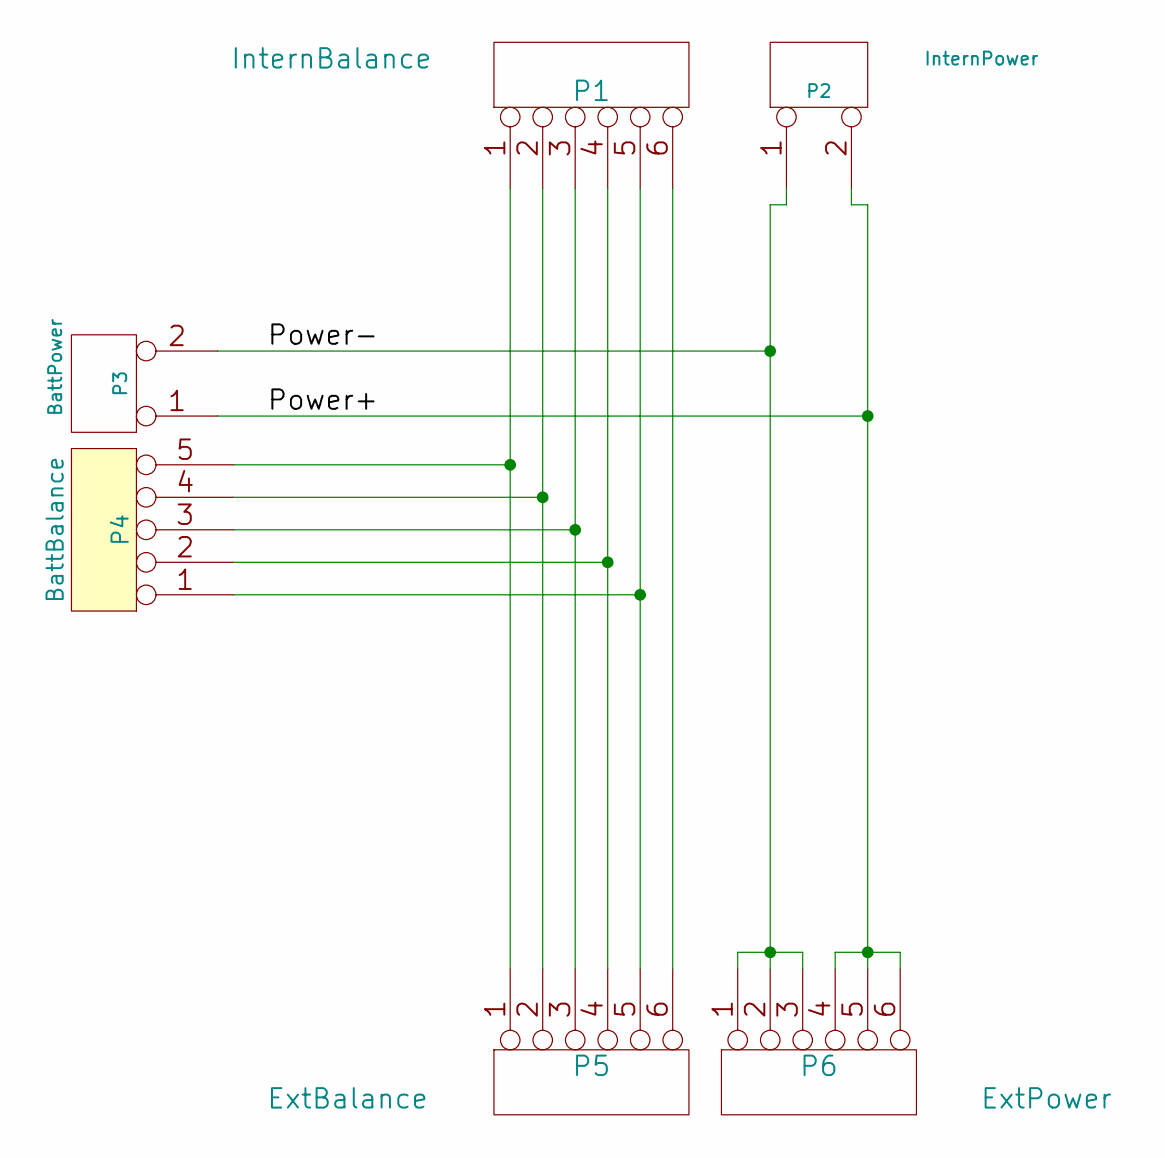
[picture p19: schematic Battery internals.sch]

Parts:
P1: InternBalance; Socket_Strip_Straight_1x06
P2: InternPower; PowerConnect_Handsolder
P3: BattPower; PowerConnect_Handsolder
P4: BattBalance; Pin_Header_Straight_1x05
P5: ExtBalance; Connector_MPX_6Pin
P6: ExtPower; Connector_MPX_6Pin

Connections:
/Power+: P2.2 (PM), P3.1, P6.4, P6.5, P6.6
/Power-: P2.1, P3.2 (PM), P6.1, P6.2, P6.3
unnamed: P1.1, P4.5, P5.1
unnamed: P1.2, P4.4, P5.2
unnamed: P1.3, P4.3, P5.3
unnamed: P1.4, P4.2, P5.4
unnamed: P1.5, P4.1, P5.5
unnamed: P1.6, P5.6

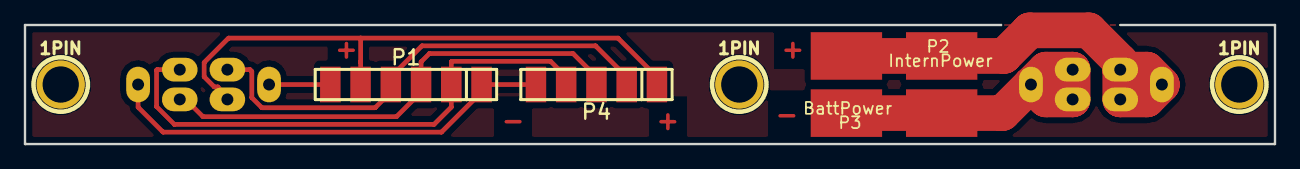
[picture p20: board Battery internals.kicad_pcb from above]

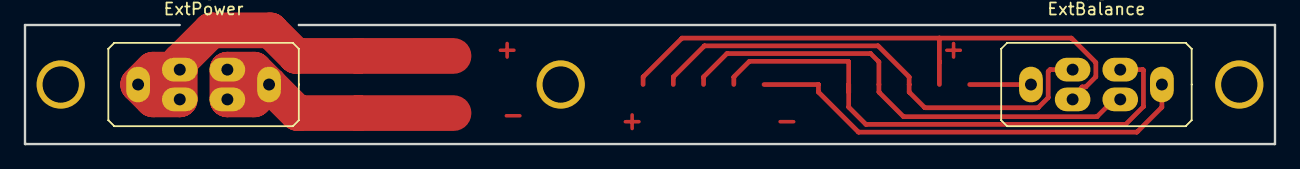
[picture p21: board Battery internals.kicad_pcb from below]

Board: 2 copper layers, 105.0 x 10.0 mm, 9 parts (2 on the bottom side), 8 nets.

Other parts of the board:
1PIN, 1PIN#2, 1PIN#3: P***; 1pin

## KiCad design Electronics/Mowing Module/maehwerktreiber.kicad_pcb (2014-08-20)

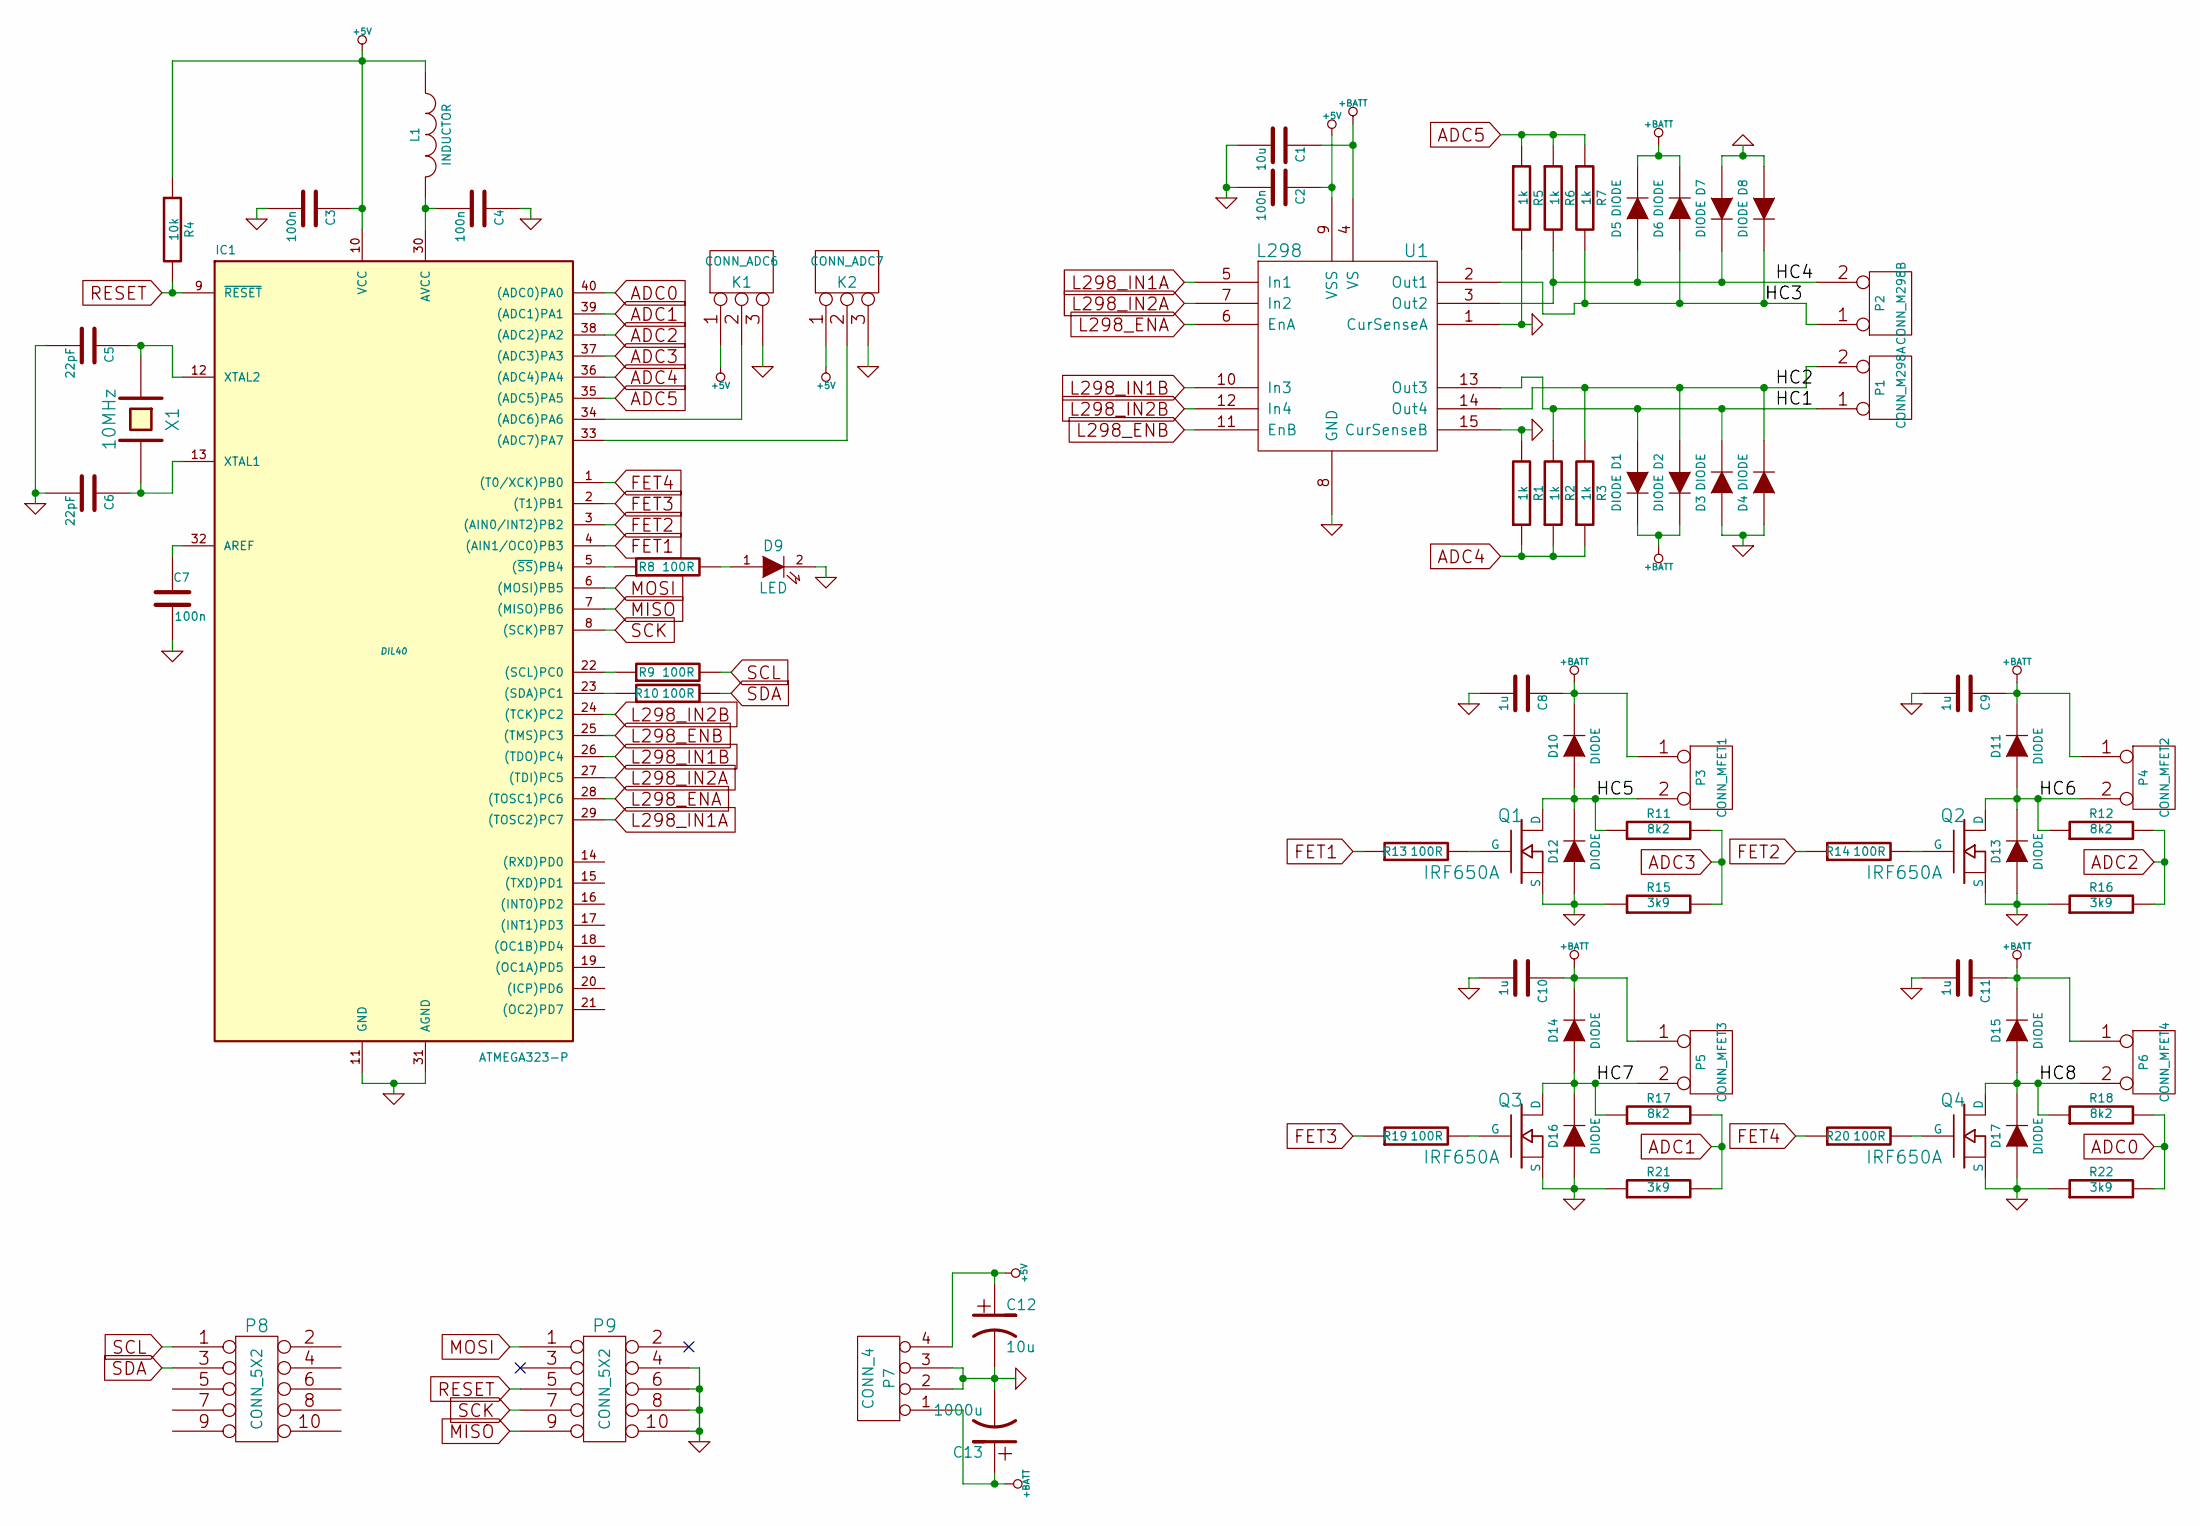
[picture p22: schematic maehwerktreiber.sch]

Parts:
C1, C12: 10u
C2, C3, C4, C7: 100n
C5, C6: 22pF
C8, C9, C10, C11: 1u
C13: 1000u
D1, D2, D3, D4, D5, D6, D7, D8, D10, D11, D12, D13, D14, D15, D16, D17: DIODE
D9: LED
IC1: ATMEGA323-P; DIL40
K1: CONN_ADC6
K2: CONN_ADC7
L1: INDUCTOR
P1: CONN_M298A
P2: CONN_M298B
P3: CONN_MFET1
P4: CONN_MFET2
P5: CONN_MFET3
P6: CONN_MFET4
P7: CONN_4
P8, P9: CONN_5X2
Q1, Q2, Q3, Q4: IRF650A
R1, R2, R3, R5, R6, R7: 1k
R4: 10k
R8, R9, R10, R13, R14, R19, R20: 100R
R11, R12, R17, R18: 8k2
R15, R16, R21, R22: 3k9
U1: L298
X1: 10MHz

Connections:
+5V: C2.1, C3.1, C12.1, IC1.10 (VCC), K1.1, K2.1, L1.1, P7.4, R4.1, U1.9 (VSS)
+BATT: C1.1, C8.1, C9.1, C10.1, C11.1, C13.1, D1.2 (K), D2.2 (K), D5.2 (K), D6.2 (K), D10.2 (K), D11.2 (K), D14.2 (K), D15.2 (K), P3.1, P4.1, P5.1, P6.1, P7.1, U1.4 (VS)
/HC1: D1.1 (A), D3.2 (K), P1.1, R2.2, U1.13 (Out3)
/HC2: D2.1 (A), D4.2 (K), P1.2 (PM), R3.2, U1.14 (Out4)
/HC3: D6.1 (A), D8.2 (K), P2.1, R7.2, U1.2 (Out1)
/HC4: D5.1 (A), D7.2 (K), P2.2 (PM), R6.2, U1.3 (Out2)
/HC5: D10.1 (A), D12.2 (K), P3.2 (PM), Q1.2 (D), R11.1
/HC6: D11.1 (A), D13.2 (K), P4.2 (PM), Q2.2 (D), R12.1
/HC7: D14.1 (A), D16.2 (K), P5.2 (PM), Q3.2 (D), R17.1
/HC8: D15.1 (A), D17.2 (K), P6.2 (PM), Q4.2 (D), R18.1
ADC0: IC1.40 ((ADC0)PA0), R18.2, R22.2
ADC1: IC1.39 ((ADC1)PA1), R17.2, R21.2
ADC2: IC1.38 ((ADC2)PA2), R12.2, R16.2
ADC3: IC1.37 ((ADC3)PA3), R11.2, R15.2
ADC4: IC1.36 ((ADC4)PA4), R1.1, R2.1, R3.1
ADC5: IC1.35 ((ADC5)PA5), R5.1, R6.1, R7.1
FET1: IC1.4 ((AIN1/OC0)PB3), R13.1
FET2: IC1.3 ((AIN0/INT2)PB2), R14.1
FET3: IC1.2 ((T1)PB1), R19.1
FET4: IC1.1 ((T0/XCK)PB0), R20.1
GND: C1.2, C2.2, C3.2, C4.1, C5.2, C6.2, C7.2, C8.2, C9.2, C10.2, C11.2, C12.2, C13.2, D3.1 (A), D4.1 (A), D7.1 (A), D8.1 (A), D9.2 (K), D12.1 (A), D13.1 (A), D16.1 (A), D17.1 (A), IC1.11 (GND), IC1.31 (AGND), K1.3, K2.3, P7.2, P7.3, P9.4, P9.6, P9.8, P9.10, Q1.3 (S), Q2.3 (S), Q3.3 (S), Q4.3 (S), R1.2, R5.2, R15.1, R16.1, R21.1, R22.1, U1.1 (CurSenseA), U1.8 (GND), U1.15 (CurSenseB)
L298_ENA: IC1.28 ((TOSC1)PC6), U1.6 (EnA)
L298_ENB: IC1.25 ((TMS)PC3), U1.11 (EnB)
L298_IN1A: IC1.29 ((TOSC2)PC7), U1.5 (In1)
L298_IN1B: IC1.26 ((TDO)PC4), U1.10 (In3)
L298_IN2A: IC1.27 ((TDI)PC5), U1.7 (In2)
L298_IN2B: IC1.24 ((TCK)PC2), U1.12 (In4)
MISO: IC1.7 ((MISO)PB6), P9.9
MOSI: IC1.6 ((MOSI)PB5), P9.1
unnamed: IC1.22 ((SCL)PC0), R9.1
unnamed: IC1.23 ((SDA)PC1), R10.1
unnamed: Q4.1 (G), R20.2
unnamed: Q3.1 (G), R19.2
unnamed: Q2.1 (G), R14.2
unnamed: D9.1 (A), R8.2
unnamed: IC1.5 ((~SS~)PB4), R8.1
unnamed: Q1.1 (G), R13.2
unnamed: IC1.33 ((ADC7)PA7), K2.2 (PM)
unnamed: IC1.34 ((ADC6)PA6), K1.2 (PM)
unnamed: C4.2, IC1.30 (AVCC), L1.2
unnamed: C7.1, IC1.32 (AREF)
unnamed: C5.1, IC1.12 (XTAL2), X1.1
unnamed: C6.1, IC1.13 (XTAL1), X1.2
RESET: IC1.9 (~RESET), P9.5, R4.2
SCK: IC1.8 ((SCK)PB7), P9.7
SCL: P8.1, R9.2
SDA: P8.3, R10.2

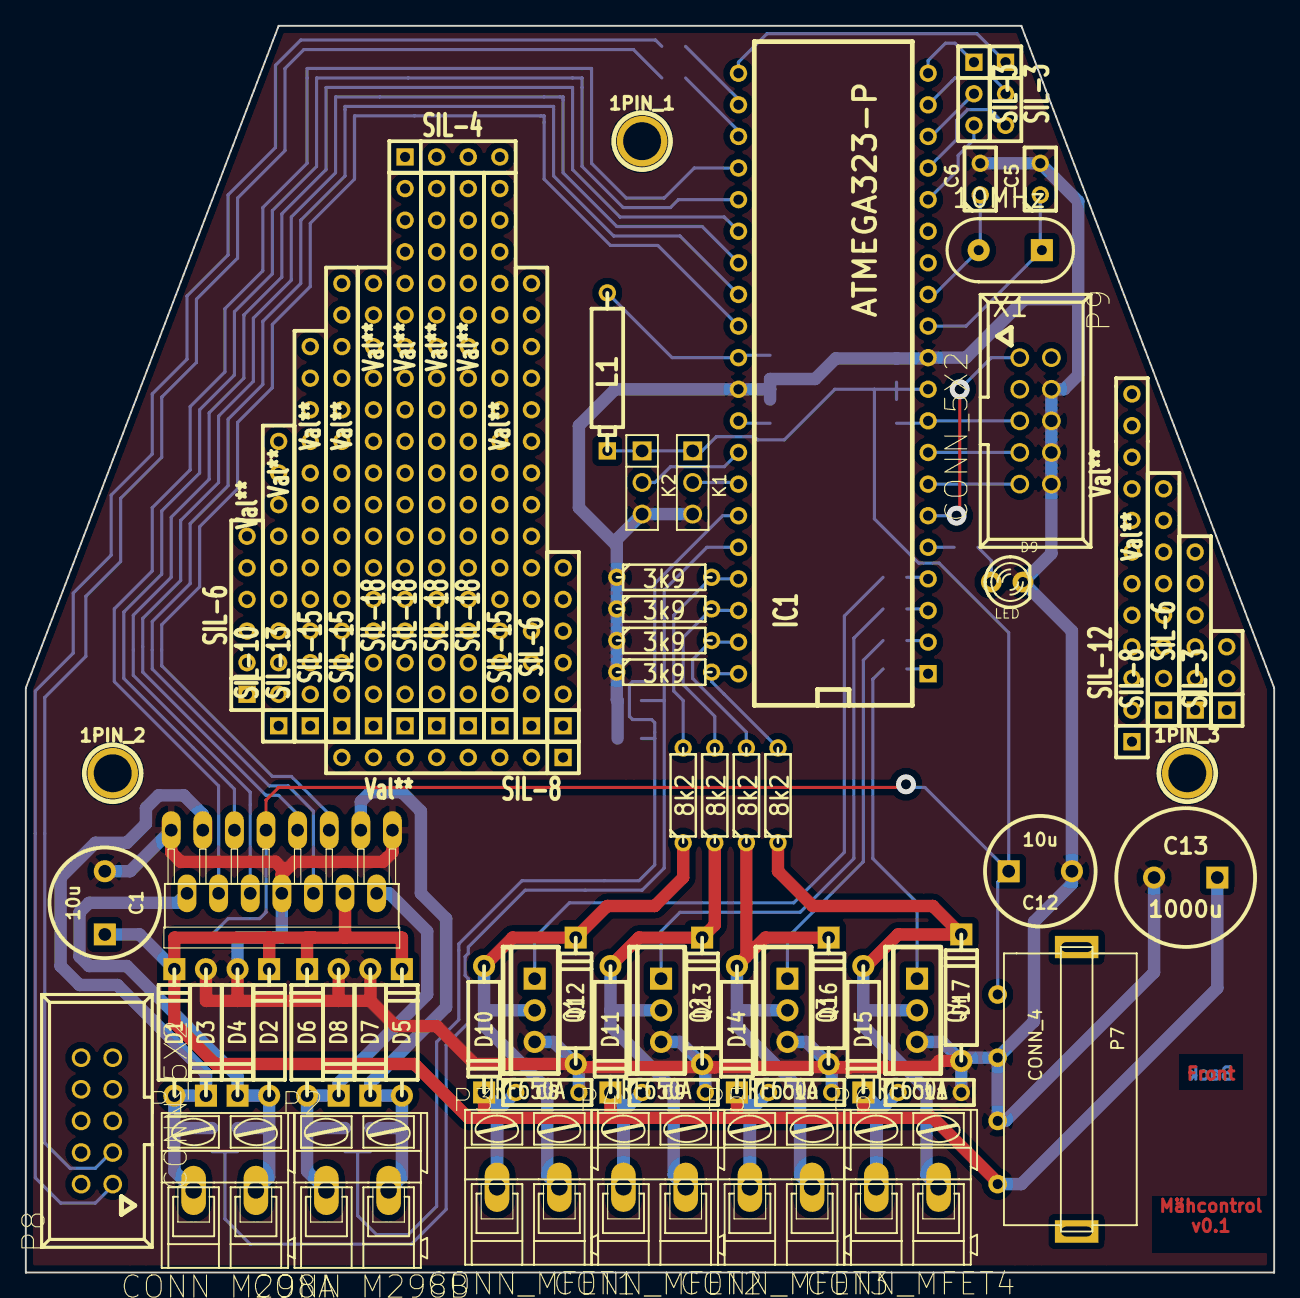
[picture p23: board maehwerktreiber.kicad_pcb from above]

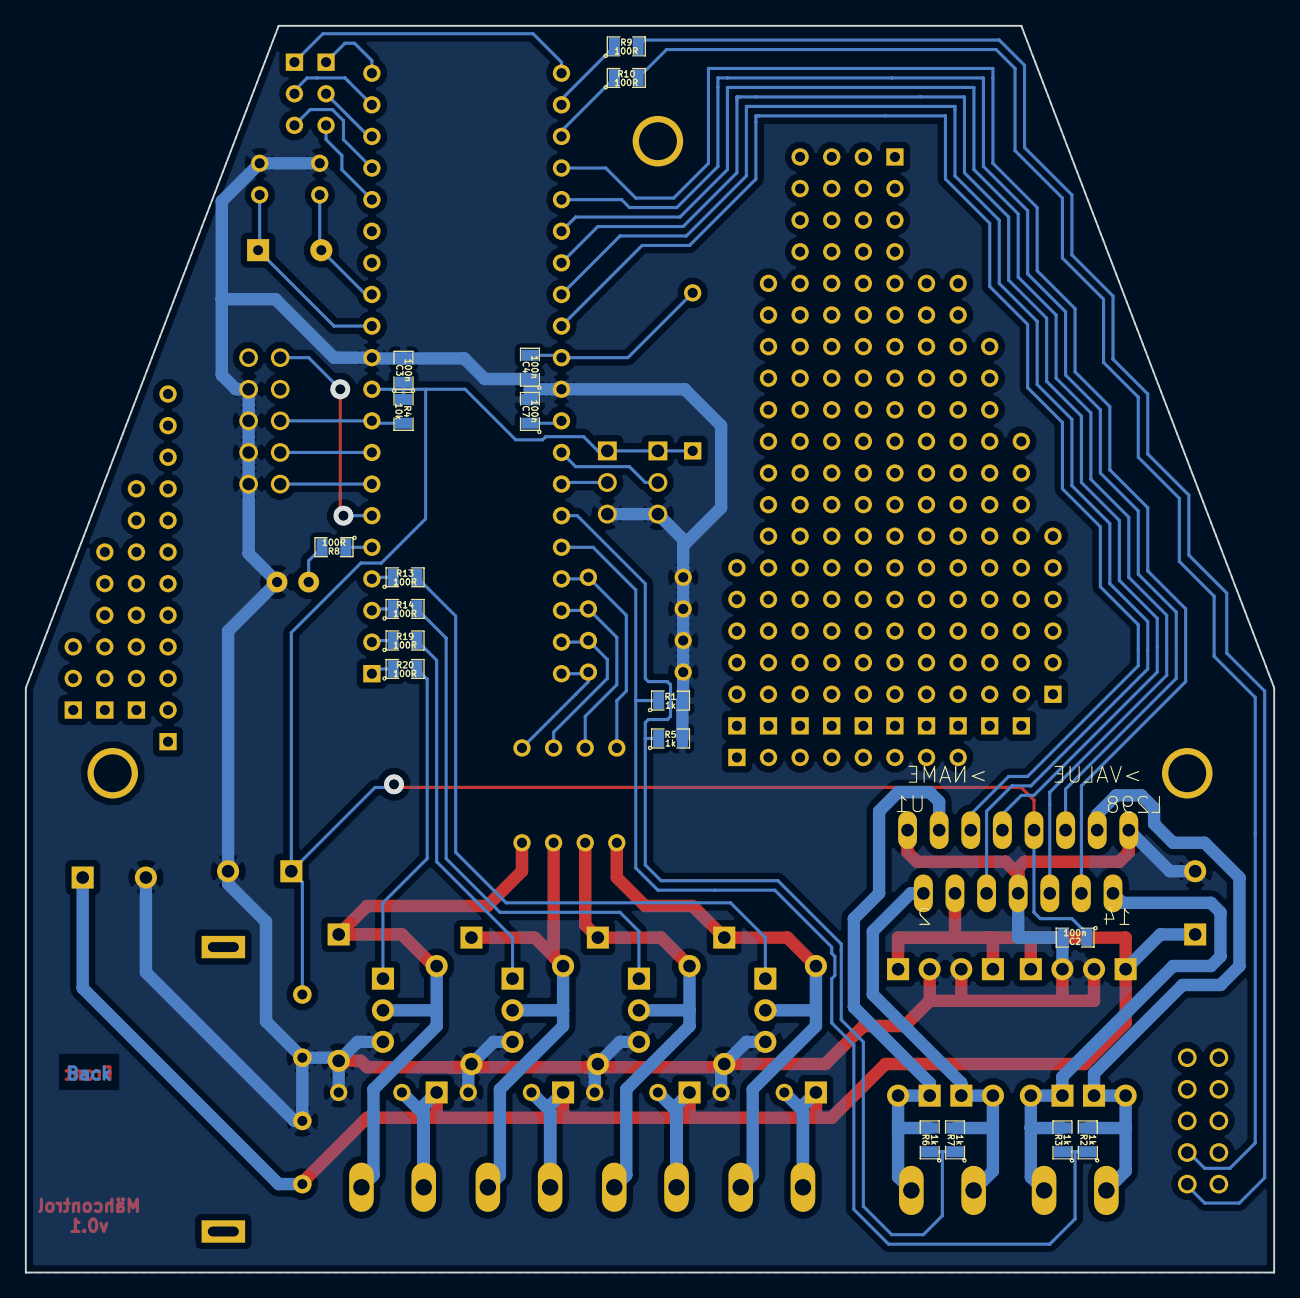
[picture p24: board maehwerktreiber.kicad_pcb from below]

Board: 2 copper layers, 100.3 x 100.2 mm, 93 parts (18 on the bottom side), 47 nets.

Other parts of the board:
1PIN_1: Hole1; 1pin
1PIN_2: Hole2; 1pin
1PIN_3: Hole3; 1pin
SIL-3, SIL-3#2, SIL-3#3: Val**; SIL-3
SIL-4: Val**; SIL-4
SIL-6, SIL-6#2, SIL-6#3: Val**; SIL-6
SIL-8, SIL-8#2: Val**; SIL-8
SIL-10: Val**; SIL-10
SIL-12: Val**; SIL-12
SIL-13: Val**; SIL-13
SIL-15, SIL-15#2, SIL-15#3: Val**; SIL-15
SIL-18, SIL-18#2, SIL-18#3, SIL-18#4: Val**; SIL-18

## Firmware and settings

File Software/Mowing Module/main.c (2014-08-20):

/*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
 */

#include <avr/io.h>
#define F_CPU 16000000UL
#include <util/delay.h>
#include <avr/interrupt.h>
#include <math.h>
#include <util/twi.h> 	    //enthält z.B. die Bezeichnungen für die Statuscodes in TWSR
#include "ADC.h"

#include "TWISLAVE.h"

#define True		1
#define False		0

#define EN_PORT		PORTC
#define EN_DDR		DDRC
#define CTRL_PORT	PORTC
#define CTRL_DDR	DDRC

#define CTRL_A1	        Pin(PC7)
#define CTRL_A2	        Pin(PC5)
#define CTRL_B1	        Pin(PC4)
#define CTRL_B2	        Pin(PC2)

#define EN_A		Pin(PC6)
#define EN_B		Pin(PC3)

#define FET_PORT        PORTB
#define FET_DDR         DDRB
#define FET_1           Pin(PB3)
#define FET_2           Pin(PB2)
#define FET_3           Pin(PB1)
#define FET_4           Pin(PB0)


#define LED_PORT	PORTB
#define LED_DDR		DDRB
#define	LED		Pin(PB4)

// Ist-Zustand (negativer Wert bei zu langsam, positiver bei zu schnell)
#define speedCorrA			0.00
#define speedCorrB			0.00
#define speedCorrFet1			0.00
#define speedCorrFet2			0.00
#define speedCorrFet3			0.00
#define speedCorrFet4			0.00


#define Set(Register, Flags)	(Register |= (Flags))
#define Clear(Register, Flags)	(Register &= ~(Flags))
#define Toggle(Register, Flags)	(Register ^= (Flags))

#define safe_Set(Register, Flags);	        {cli();(Register |= (Flags));sei(); }
#define safe_Clear(Register, Flags);	        {cli();(Register &= ~(Flags));sei();}
#define safe_Toggle(Register, Flags);	{cli();(Register ^= (Flags));sei(); }

#define Pin(Pxx) (1<<(Pxx))

#define SLAVE_ADRESSE (0x32<<1) //Die Slave-Adresse

#define I2C_STATUS		0
#define I2C_CMD			1
#define I2C_CMD_ARG1	        2
#define I2C_CMD_ARG2	        3
#define I2C_CMD_ARG3	        4
#define I2C_CMD_ARG4	        5
#define I2C_FET1power		6
#define I2C_FET1speed		7
#define I2C_FET1spdmeas	        8
#define I2C_FET2power		9
#define I2C_FET2speed		10
#define I2C_FET2spdmeas	        11
#define I2C_FET3power		12
#define I2C_FET3speed		13
#define I2C_FET3spdmeas	        14
#define I2C_FET4power		15
#define I2C_FET4speed		16
#define I2C_FET4spdmeas	        17
#define I2C_Apower		18
#define I2C_Aspeed		19
#define I2C_Aspdmeas	        20
#define I2C_Bpower		21
#define I2C_Bspeed		22
#define I2C_Bspdmeas	        23
#define I2C_height              24
#define I2C_heightmeas          25

#define STATUS_OK		1
#define STATUS_ERR		2

#define NOCMD			0
#define CMD_STOP		1
#define CMD_FET1SPD             2
#define CMD_FET2SPD             3
#define CMD_FET3SPD             4
#define CMD_FET4SPD             5
#define CMD_HEIGHT              6


int8_t power_A=0, power_B=0, power_Fet1=0, power_Fet2=0, power_Fet3=0, power_Fet4=0;
int8_t speed_A=0, speed_B=0, speed_Fet1=0, speed_Fet2=0, speed_Fet3=0, speed_Fet4=0;
int8_t accl_A=0, accl_B=0, accl_Fet1=0, accl_Fet2=0, accl_Fet3=0, accl_Fet4=0;
int8_t spdmeas_A=0, spdmeas_B=0, spdmeas_Fet1=0, spdmeas_Fet2=0, spdmeas_Fet3=0, spdmeas_Fet4=0;


type_ADC_CHANNEL ADC_A, ADC_B, ADC_FET1, ADC_FET2, ADC_FET3, ADC_FET4, ADC_HEIGHT;

float height_meas;
float height = 50;

void pwm (void);

int main (void)
{
    
        // ADC A
                ADC_A.samples	        = 3;
                ADC_A.uref		= ADC_REF_AVCC;
                ADC_A.channel	        = 5;
                ADC_A.minValueIs        = -10;
                ADC_A.maxValueIs        = 110;
                ADC_A.blocking	        = True;
                
        // ADC B
                ADC_B.samples	        = 3;
                ADC_B.uref		= ADC_REF_AVCC;
                ADC_B.channel	        = 4;
                ADC_B.minValueIs        = -10;
                ADC_B.maxValueIs        = 110;
                ADC_B.blocking	        = True;
                
        // ADC FET1
                ADC_FET1.samples	= 1;
                ADC_FET1.uref		= ADC_REF_AVCC;
                ADC_FET1.channel	= 3;
                ADC_FET1.minValueIs     = 0;
                ADC_FET1.maxValueIs     = 100;
                ADC_FET1.blocking	= True;
                
        // ADC FET2
                ADC_FET2.samples	= 1;
                ADC_FET2.uref		= ADC_REF_AVCC;
                ADC_FET2.channel	= 2;
                ADC_FET2.minValueIs     = 0;
                ADC_FET2.maxValueIs     = 100;
                ADC_FET2.blocking	= True;
                
        // ADC FET3
                ADC_FET3.samples	= 1;
                ADC_FET3.uref		= ADC_REF_AVCC;
                ADC_FET3.channel	= 1;
                ADC_FET3.minValueIs     = 0;
                ADC_FET3.maxValueIs     = 100;
                ADC_FET3.blocking	= True;
                
        // ADC FET4
                ADC_FET4.samples	= 1;
                ADC_FET4.uref		= ADC_REF_AVCC;
                ADC_FET4.channel	= 0;
                ADC_FET4.minValueIs     = 0;
                ADC_FET4.maxValueIs     = 100;
                ADC_FET4.blocking	= True;
                
        // ADC HEIGHT
                ADC_HEIGHT.samples	= 1;
                ADC_HEIGHT.uref		= ADC_REF_AVCC;
                ADC_HEIGHT.channel	= 7;
                ADC_HEIGHT.minValueIs     = -10;
                ADC_HEIGHT.maxValueIs     = 110;
                ADC_HEIGHT.blocking	= True;

        ADC_INIT(&ADC_A, True);
        ADC_INIT(&ADC_B, False);
        ADC_INIT(&ADC_FET1, False);
        ADC_INIT(&ADC_FET2, False);
        ADC_INIT(&ADC_FET3, False);
        ADC_INIT(&ADC_FET4, False);
        ADC_INIT(&ADC_HEIGHT, False);
        
        safe_Set(CTRL_DDR, CTRL_A1 | CTRL_A2);
        safe_Set(EN_DDR,  EN_A);
        
        
        safe_Set(EN_PORT, EN_A);
        safe_Clear(CTRL_PORT,  CTRL_A1 | CTRL_A2);
       
        
        ///float set = 0;
        ///while(1)
        ///{
        ///        for( uint16_t i = 0; i<6000; i++)
        ///        {
        ///                float height = ADC_MEASURE(&ADC_HEIGHT);
        ///                
        ///                if(height < set-1)
        ///                {
        ///                        safe_Set(CTRL_PORT, CTRL_A1);
        ///                        safe_Clear(CTRL_PORT,  CTRL_A2);
        ///                }
        ///                else 
        ///                {
        ///                        if(height > set+1)
        ///                        {
        ///                                safe_Set(CTRL_PORT, CTRL_A2);
        ///                                safe_Clear(CTRL_PORT,  CTRL_A1);
        ///                        }
        ///                        else 
        ///                        {
        ///                                //safe_Clear(CTRL_PORT,  CTRL_A1 | CTRL_A2);
        ///                        }
        ///                }
        ///                
        ///                _delay_ms(1);
        ///                
        ///                safe_Clear(CTRL_PORT,  CTRL_A1 | CTRL_A2);
        ///                //_delay_ms(1);
        ///        }
        ///        if (set == 0)
        ///                set = 100;
        ///        else
        ///                set = 0;
        ///}
        
        safe_Set(LED_DDR, LED);
        safe_Set(LED_PORT, LED);
        
        safe_Set(FET_DDR, FET_1 | FET_2 | FET_3 | FET_4);
        safe_Clear(FET_PORT, FET_1 | FET_2 | FET_3 | FET_4); // Motoren aus
        
        _delay_ms(1000);
        
        {
                ADC_FET1.samples	= 10;
                ADC_FET2.samples	= 10;
                ADC_FET3.samples	= 10;
                ADC_FET4.samples	= 10;
                float tmp1 = ADC_MEASURE(&ADC_FET1);
                float tmp2 = ADC_MEASURE(&ADC_FET2);
                float tmp3 = ADC_MEASURE(&ADC_FET3);
                float tmp4 = ADC_MEASURE(&ADC_FET4);
                float tmp_avgctr = 0;
                float tmp_avg = 0;
                
                if(tmp1 > 30)
                {
                        tmp_avg += tmp1;
                        tmp_avgctr++;
                }
                
                if(tmp2 > 30)
                {
                        tmp_avg += tmp2;
                        tmp_avgctr++;
                }
                
                if(tmp3 > 30)
                {
                        tmp_avg += tmp3;
                        tmp_avgctr++;
                }
                
                if(tmp4 > 30)
                {
                        tmp_avg += tmp4;
                        tmp_avgctr++;
                }
                
                tmp_avg /= tmp_avgctr;
                
                ADC_FET1.maxValueIs     = (100/tmp_avg)*100;
                ADC_FET2.maxValueIs     = (100/tmp_avg)*100;
                ADC_FET3.maxValueIs     = (100/tmp_avg)*100;
                ADC_FET4.maxValueIs     = (100/tmp_avg)*100;
                
                ADC_FET1.samples	= 2;
                ADC_FET2.samples	= 2;
                ADC_FET3.samples	= 2;
                ADC_FET4.samples	= 2;
        }
        
        //safe_Set(EN_DDR, EN_A | EN_B);
        //safe_Set(CTRL_DDR, CTRL_A1 | CTRL_A2 | CTRL_B1 | CTRL_B2);
        
        
   ///     // Timer 0 -> 100us angepeilt
   ///             /// FCPU = 16Mhz -> 62.5ns
   ///             // Vorteiler 8 -> 2Mhz bzw. 0.5us
   ///                     TCCR0 = (1<CS02) | (0<<CS01) | (1<<CS00);      /// /8
   ///             // CTC-Modus (bis OCR0 zaehlen, isr und dann wieder bei 0 anfangen)
   ///                     TCCR0 |= (1<<WGM01) | (0<<WGM00);
   ///             // Von 0-199 in 0.5us-Schritten zaehlen -> 200*0.5us = 0.1ms
   ///                     OCR0 = 40-1;
   ///             // Output compare match interrupt enable
   ///                     TIMSK |= (1<<OCIE0);
   ///     
   ///     sei();
        
        

        //TWI als Slave mit Adresse slaveadr starten
        init_twi_slave(SLAVE_ADRESSE);

        i2cdata[I2C_FET1power	] = 100;
        i2cdata[I2C_FET1speed	] = 100;
        i2cdata[I2C_FET1spdmeas	] = 100;
        i2cdata[I2C_FET2power	] = 100;
        i2cdata[I2C_FET2speed	] = 100;
        i2cdata[I2C_FET2spdmeas	] = 100;
        i2cdata[I2C_FET3power	] = 100;
        i2cdata[I2C_FET3speed	] = 100;
        i2cdata[I2C_FET3spdmeas	] = 100;
        i2cdata[I2C_FET4power	] = 100;
        i2cdata[I2C_FET4speed	] = 100;
        i2cdata[I2C_FET4spdmeas	] = 100;
        i2cdata[I2C_Apower	] = 100;
        i2cdata[I2C_Aspeed	] = 100;
        i2cdata[I2C_Aspdmeas	] = 100;
        i2cdata[I2C_Bpower	] = 100;
        i2cdata[I2C_Bspeed	] = 100;
        i2cdata[I2C_Bspdmeas	] = 100;
        	
        uint16_t myscaler = 0;
        while(1)
        {
                if(i2cdata[I2C_CMD] != NOCMD)
                {
                        switch(i2cdata[I2C_CMD])
                        {
                                case CMD_STOP:
                                        speed_Fet1 = 0;
                                        speed_Fet2 = 0;
                                        speed_Fet3 = 0;
                                        speed_Fet4 = 0;
                                        speed_A = 0;
                                        speed_B = 0;
                                        power_Fet1 = 0;
                                        power_Fet2 = 0;
                                        power_Fet3 = 0;
                                        power_Fet4 = 0;
                                        power_A = 0;
                                        power_B = 0;
                                        break;
                                case CMD_FET1SPD:
                                        speed_Fet1 = i2cdata[I2C_CMD_ARG1];
                                        break;
                                case CMD_FET2SPD:
                                        speed_Fet2 = i2cdata[I2C_CMD_ARG1];
                                        break;
                                case CMD_FET3SPD:
                                        speed_Fet3 = i2cdata[I2C_CMD_ARG1];
                                        break;
                                case CMD_FET4SPD:
                                        speed_Fet4 = i2cdata[I2C_CMD_ARG1];
                                        break;
                                case CMD_HEIGHT:
                                        height = i2cdata[I2C_CMD_ARG1];
                                        if(height>100)
                                                height = 100;
                                        if(height<0)
                                                height = 0;
                                        break;
                        }
                        i2cdata[I2C_CMD] = NOCMD;
                }
                //else
                //        _delay_us(1); // Grund: der rapsi schreibt zuerst I2C_CMD und dann I2C_CMD_ARG.. D.h. der Request wird schon verarbeitet wenn ernoch garnicht vollständig gesendet wurde. -> Shit
                
                

                i2cdata[I2C_FET1power	] = 100+  power_Fet1;
                i2cdata[I2C_FET1speed	] = 000+  speed_Fet1;
                i2cdata[I2C_FET1spdmeas	] = 100+spdmeas_Fet1;
                i2cdata[I2C_FET2power	] = 100+  power_Fet2;
                i2cdata[I2C_FET2speed	] = 000+  speed_Fet2;
                i2cdata[I2C_FET2spdmeas	] = 100+spdmeas_Fet2;
                i2cdata[I2C_FET3power	] = 100+  power_Fet3;
                i2cdata[I2C_FET3speed	] = 000+  speed_Fet3;
                i2cdata[I2C_FET3spdmeas	] = 100+spdmeas_Fet3;
                i2cdata[I2C_FET4power	] = 100+  power_Fet4;
                i2cdata[I2C_FET4speed	] = 000+  speed_Fet4;
                i2cdata[I2C_FET4spdmeas	] = 100+spdmeas_Fet4;
                i2cdata[I2C_Apower	] = 100+  power_A;
                i2cdata[I2C_Aspeed	] = 100+  speed_A;
                i2cdata[I2C_Aspdmeas	] = 100+spdmeas_A;
                i2cdata[I2C_Bpower	] = 100+  power_B;
                i2cdata[I2C_Bspeed	] = 100+  speed_B;
                i2cdata[I2C_Bspdmeas	] = 100+spdmeas_B;
                i2cdata[I2C_height	] = height;
                i2cdata[I2C_heightmeas	] = height_meas;
                
                pwm();
                
                /////_delay_ms(100);
                ///if(RedLEDCountdown > 0)
                ///{
                ///        RedLEDCountdown--;
                ///        Set(LED_PORT, LED_RD); // Red LED on
                ///}
                ///else
                ///        Clear(LED_PORT, LED_RD); // Red LED off
                ///        
                
                //cli();
                //safe_Toggle(LED_PORT, LED_GN);
                //sei();
                //_delay_ms(10);
                if(myscaler > 10000)
                {
                        myscaler = 0;
                        safe_Toggle(LED_PORT, LED);
                }
                
                myscaler++;
        }
        
        return 0;
}

#define PowerTolerance  0
int8_t calcPower(int16_t powerNow, int8_t spdMeas, int8_t speed)
{
	if((speed-spdMeas)>PowerTolerance)
		powerNow += (speed-spdMeas)/4;
	else if((speed-spdMeas)<-PowerTolerance)
		powerNow += (speed-spdMeas)/4;
	if(powerNow>100)
		powerNow=100;
	if(powerNow<-100)
		powerNow=-100;
	if(abs(powerNow)>abs(speed*speed*speed))
	{
		powerNow = speed*speed*speed;
	}
        
	return powerNow;
}

#define FET_MAXPWR      70
#define FET_MAXPWRABOVE 6 // speed
#define FET_PWRONSTART  40
#define FetPowerTolerance  0
int8_t calcPowerFET(int16_t powerNow, int8_t spdMeas, int8_t speed, int8_t accl)
{
        if( speed == 0)
                return 0;
                
        //return speed/2;
                
        int8_t thismax = 0;
        if( spdMeas >= FET_MAXPWRABOVE )
                thismax = FET_MAXPWR;
        else
        {
                float tmp=0;
                tmp = spdMeas;
                tmp /= FET_MAXPWRABOVE;
                tmp *= (FET_MAXPWR - FET_PWRONSTART);
                tmp += FET_PWRONSTART;
                thismax = tmp;
                //((float)(FET_MAXPWR-FET_PWRONSTART)*(float)(spdMeas/FET_MAXPWRABOVE))+FET_PWRONSTART;
        }
        
        int8_t diff = (speed-spdMeas);
        ///if( diff > 0 )
        ///{
        ///        if( accl <= diff/8)
        ///                powerNow += diff/2+1;
        ///}
        ///else
        ///{
        ///        if( accl >= diff/8)
        ///                powerNow += diff/2-1;
        ///}
        
        if( diff>0)
                powerNow = diff*2;
        else
                powerNow = 1;
        
        //if(speed > spdMeas && accl < 2)
        //        powerNow++;
        //if(speed < spdMeas && accl > -2)
        //        powerNow--;
	
        ///if((speed-spdMeas)>FetPowerTolerance)
	///	powerNow += (speed-spdMeas);
	///else if((speed-spdMeas)<-FetPowerTolerance)
	///	powerNow += (speed-spdMeas);
        
        //int8_t diff = (speed-spdMeas);
        //if( diff < 10 )
        //        powerNow = diff*2;
        //else
        //        powerNow = diff;
        
        
        if(powerNow>thismax)
                powerNow = thismax;
	if(powerNow>100)
		powerNow=100;
	if(powerNow<0)
		powerNow=0;
	///if(abs(powerNow)>abs(speed*speed*speed))
	///{
	///	powerNow = speed*speed*speed;
	///}
        
	return powerNow;
}


uint8_t Channelselect = 0;
#define TimeDiff	1

#define postscaler  32
uint8_t postsclctr = 0;
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
int main (void)
{
        Set(FET_DDR, FET_1 | FET_2 | FET_3 | FET_4);
        Clear(FET_PORT, FET_1 | FET_2 | FET_3 | FET_4);
        
        Set(LED_DDR, LED);
        while(True)
        {
                Toggle(LED_PORT, LED);
                Set(FET_PORT, FET_4);
                _delay_ms(1000);
                Clear(FET_PORT, FET_4);
                _delay_ms(1000);
        }
        return 0;
}
//*/

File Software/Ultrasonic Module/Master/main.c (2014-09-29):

/*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
 */

#include <avr/io.h>
#define F_CPU 12000000UL
#include <util/delay.h>
#include <avr/interrupt.h>
#include <math.h>
#include <util/twi.h> 	    //enthält z.B. die Bezeichnungen für die Statuscodes in TWSR
#include "TWISLAVE.h"
#include "LCD.h"


#define ADDR_SELF       (1<<4)
#define ADDR_MASTER     ADDR_SELF
#define ADDR_NODE_A     (2<<4)

#define DATA_DOECHO     (1)
#define DATA_ECHOREPL   (2)

#define Rx_PORT         PORTD
#define Rx_DDR          DDRD
#define Rx_PIN          PIND
#define Rx_highFlanc    Pin(PD2)
#define Rx_highvalid    Pin(PD3)

#define Tx_DDR          DDRB
#define Tx_PORT         PORTB
#define Tx1             Pin(PB1)         
#define Tx2             Pin(PB2)

#define Set(Register, Flags)	(Register |= (Flags))
#define Clear(Register, Flags)	(Register &= ~(Flags))
#define Toggle(Register, Flags)	(Register ^= (Flags))

#define safe_Set(Register, Flags);	        {cli();(Register |= (Flags));sei(); }
#define safe_Clear(Register, Flags);	        {cli();(Register &= ~(Flags));sei();}
#define safe_Toggle(Register, Flags);	{cli();(Register ^= (Flags));sei(); }

#define Pin(Pxx) (1<<(Pxx))

#define True		1
#define False		0

uint8_t Receiveing40KHz=False;
uint8_t tmp = 0;

void Tx_init (void)
{
        Set(Tx_DDR, Tx1);
        Set(Tx_DDR, Tx2);
        Set(Tx_PORT, Tx1);
        Clear(Tx_PORT, Tx2);
}

void Tx (uint16_t data)
{
 
        uint8_t stream[1+2+8+2+1];
        uint8_t i, j;
        stream[0]=0;
        stream[1]=1;
        stream[2]=1;
        for(i=0; i<8; i++)
        {
                stream[1+2+i] = (data&(1<<i))?1:0;
        }
        uint8_t parity;
        //parity = 3-(data&0b11);
        parity = 0;
        parity ^= (data>>0)&0b11;
        parity ^= (data>>2)&0b11;
        parity ^= (data>>4)&0b11;
        parity ^= (data>>6)&0b11;
        stream[11]= (parity&0b01)?1:0;
        stream[12]= (parity&0b10)?1:0;
        stream[13]=1;
        
        for(i=0; i<1+2+8+2+1; i++)
        {
                for(j=0; j<40; j++)
                {
                        Clear(Tx_PORT, Tx1);
                        Set(Tx_PORT, Tx2);
                        _delay_us(12);
                        Set(Tx_PORT, Tx1);
                        Clear(Tx_PORT, Tx2);
                        _delay_us(12);
                }
                if(stream[i])
                        _delay_us(11);
                //else
                //        _delay_us(24);
                
        }
        
        
}

void Rx_init (void)
{
        //// INT1
        //MCUCR |= (1 << ISC11) | (1 << ISC10);    // set INT1 to trigger on postive flanc
        //GICR |= (1 << INT1);      // Turns on INT0
        //sei();                    // turn on interrupts
        
        Clear(Rx_DDR, Rx_highFlanc | Rx_highvalid);

        // TIMER0
        TCCR0 |= (1 << CS02) | (0 << CS01) | (0 << CS00); // prescaler=256 -> 1 count = 21.333us
        TCNT0 = 0;
        
        // TIMER1
        TCCR1B |= (0 << CS12) | (1 << CS11) | (1 << CS10); // prescaler=64 -> 1 count = 5.3333us
        TCNT1 = 0;
}

uint8_t Rx (uint16_t timeoutms)
{
        DDRB |= (1<<PB1);
        uint8_t tries = 0;
        uint8_t parity=0, i=0;
        uint16_t downstream = 0;
        uint8_t data;
        uint8_t tmp, tmp2;
        uint16_t tmp3;
        uint16_t timeoutctrms = 0;
        
        Rx_start:
        PORTB |= (1<<PB1);
        //_delay_ms(4);
        tries++;
                TCNT0 = 0;
                while( (Rx_PIN&Rx_highvalid) == 0 )
                {
                        if( TCNT0 >= 188 ) // 4ms
                        {
                                TCNT0 = 0;
                                timeoutctrms += 4;
                                if( timeoutctrms > timeoutms )
                                        return 0;
                        }
                }
                
        // beginning bit ends
                TCNT0 = 0;
                while( (Rx_PIN&Rx_highvalid) || (TCNT0 <= 47) ) //1ms
                {
                        if( TCNT0 >= 141 ) // 3ms
                        {
                                timeoutctrms += 3;
                                if( timeoutctrms > timeoutms )
                                        return 0;
                                goto Rx_start;
                        }
                }
        
        
                
        PORTB ^= (1<<PB1);
                
        // startbit 1: beginning
                TCNT0 = 0;
                while( (TCNT0 <= 5) ); // 0.1ms
                while( (Rx_PIN&Rx_highFlanc) == 0 )
                {
                        if( TCNT0 >= 23 ) // 0.5ms
                                goto Rx_start;
                }
                
        PORTB ^= (1<<PB1);
                
                if( (Rx_PIN&Rx_highvalid) )
                        goto Rx_start;
                        
                
                        
                TCNT0 = 0;
                
        
                
                
        
                        
        // startbit 1: end
                while( (Rx_PIN&Rx_highFlanc)  )
                {
                        if( TCNT0 >= 47 ) // 1ms
                                goto Rx_start;
                }
                
                
        
                
        // startbit 2: beginning
                while( (Rx_PIN&Rx_highFlanc) == 0 )
                {
                        if( TCNT0 > 47+5 ) // 1ms
                                goto Rx_start;
                }
                if( (Rx_PIN&Rx_highvalid) )
                        goto Rx_start;
                if( TCNT0 < 47-5 ) // 1ms
                                goto Rx_start;
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

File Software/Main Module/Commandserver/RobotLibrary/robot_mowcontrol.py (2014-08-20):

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

from RobotLibrary import i2c as i2c

I2C_STATUS              = 0
I2C_CMD                 = 1
I2C_CMD_ARG1            = 2
I2C_CMD_ARG2            = 3
I2C_CMD_ARG3            = 4
I2C_CMD_ARG4            = 5
I2C_FET1power           = 6
I2C_FET1speed           = 7
I2C_FET1spdmeas         = 8
I2C_FET2power           = 9
I2C_FET2speed           = 10
I2C_FET2spdmeas         = 11
I2C_FET3power           = 12
I2C_FET3speed           = 13
I2C_FET3spdmeas         = 14
I2C_FET4power           = 15
I2C_FET4speed           = 16
I2C_FET4spdmeas         = 17
I2C_Apower              = 18
I2C_Aspeed              = 19
I2C_Aspdmeas            = 20
I2C_Bpower              = 21
I2C_Bspeed              = 22
I2C_Bspdmeas            = 23

NOCMD                   = 0
CMD_STOP                = 1
CMD_FET1SPD             = 2
CMD_FET2SPD             = 3
CMD_FET3SPD             = 4
CMD_FET4SPD             = 5

SLAVE_ADDRESS = 0x32

def STOP():
        i2c.SETSLAVE(SLAVE_ADDRESS)
        i2c.WRITECMDWAIT(CMD_STOP)
        
def SET_FET1(speed):
        i2c.SETSLAVE(SLAVE_ADDRESS)
        i2c.WRITECMDWAIT(CMD_FET1SPD, speed)

def SET_FET2(speed):
        i2c.SETSLAVE(SLAVE_ADDRESS)
        i2c.WRITECMDWAIT(CMD_FET2SPD, speed)
        
def SET_FET3(speed):
        i2c.SETSLAVE(SLAVE_ADDRESS)
        i2c.WRITECMDWAIT(CMD_FET3SPD, speed)
        
def SET_FET4(speed):
        i2c.SETSLAVE(SLAVE_ADDRESS)
        i2c.WRITECMDWAIT(CMD_FET4SPD, speed)
        
def GET_STATUS():
        i2c.SETSLAVE(SLAVE_ADDRESS)
        status  = {}
        status["FET1power"      ] = int(i2c.READ(I2C_FET1power   ))-100
        status["FET1speed"      ] = int(i2c.READ(I2C_FET1speed   ))
        status["FET1spdmeas"    ] = int(i2c.READ(I2C_FET1spdmeas ))-100
        status["FET2power"      ] = int(i2c.READ(I2C_FET2power   ))-100
        status["FET2speed"      ] = int(i2c.READ(I2C_FET2speed   ))
        status["FET2spdmeas"    ] = int(i2c.READ(I2C_FET2spdmeas ))-100
        status["FET3power"      ] = int(i2c.READ(I2C_FET3power   ))-100
        status["FET3speed"      ] = int(i2c.READ(I2C_FET3speed   ))
        status["FET3spdmeas"    ] = int(i2c.READ(I2C_FET3spdmeas ))-100
        status["FET4power"      ] = int(i2c.READ(I2C_FET4power   ))-100
        status["FET4speed"      ] = int(i2c.READ(I2C_FET4speed   ))
        status["FET4spdmeas"    ] = int(i2c.READ(I2C_FET4spdmeas ))-100
        status["Apower"         ] = int(i2c.READ(I2C_Apower      ))-100
        status["Aspeed"         ] = int(i2c.READ(I2C_Aspeed      ))-100
        status["Aspdmeas"       ] = int(i2c.READ(I2C_Aspdmeas    ))-100
        status["Bpower"         ] = int(i2c.READ(I2C_Bpower      ))-100
        status["Bspeed"         ] = int(i2c.READ(I2C_Bspeed      ))-100
        status["Bspdmeas"       ] = int(i2c.READ(I2C_Bspdmeas    ))-100
        
        return status
        
        

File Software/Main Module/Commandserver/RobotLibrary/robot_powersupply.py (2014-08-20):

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

from RobotLibrary import i2c as i2c

I2C_STATUS		= 0
I2C_CMD			= 1
I2C_CMD_ARG1	        = 2
I2C_CMD_ARG2	        = 3
I2C_CMD_ARG3	        = 4
I2C_CMD_ARG4	        = 5
I2C_CELL1VOLTl          = 6
I2C_CELL1VOLTh          = 7
I2C_CELL2VOLTl          = 8
I2C_CELL2VOLTh          = 9
I2C_CELL3VOLTl          = 10
I2C_CELL3VOLTh          = 11
I2C_CELL4VOLTl          = 12
I2C_CELL4VOLTh          = 13
I2C_CELL1PERC           = 14
I2C_CELL2PERC           = 15
I2C_CELL3PERC           = 16
I2C_CELL4PERC           = 17

NOCMD			= 0
CMD_STOP		= 1
CMD_WRITEREG	= 2
CMD_USERANGLE	= 3
CMD_USERSPEED	= 4
CMD_MOTORL		= 5
CMD_MOTORR		= 6
CMD_MOVEMODE	= 7

MoveMode_Torque = 1
MoveMode_Speed	= 2

SLAVE_ADDRESS = 0x30

def GET_BAT():
        i2c.SETSLAVE(SLAVE_ADDRESS)
        bat = {}
        bat["CELL1"] = {}
        bat["CELL1"]["VOLT"] = (i2c.READ(I2C_CELL1VOLTh)*128+i2c.READ(I2C_CELL1VOLTl))/1000
        bat["CELL1"]["PERCENTAGE"] = i2c.READ(I2C_CELL1PERC)
        bat["CELL2"] = {}
        bat["CELL2"]["VOLT"] = (i2c.READ(I2C_CELL2VOLTh)*128+i2c.READ(I2C_CELL2VOLTl))/1000
        bat["CELL2"]["PERCENTAGE"] = i2c.READ(I2C_CELL2PERC)
        bat["CELL3"] = {}
        bat["CELL3"]["VOLT"] = (i2c.READ(I2C_CELL3VOLTh)*128+i2c.READ(I2C_CELL3VOLTl))/1000
        bat["CELL3"]["PERCENTAGE"] = i2c.READ(I2C_CELL3PERC)
        bat["CELL4"] = {}
        bat["CELL4"]["VOLT"] = (i2c.READ(I2C_CELL4VOLTh)*128+i2c.READ(I2C_CELL4VOLTl))/1000
        bat["CELL4"]["PERCENTAGE"] = i2c.READ(I2C_CELL4PERC)
        
        return bat
	
def GET_STATUS():
	i2c.SETSLAVE(SLAVE_ADDRESS)
	status  = {}
	#status["angle"] = int(i2c.READ(I2C_ANGLE))-100
	#status["FLpower"]   = int(i2c.READ(I2C_FLpower))-100
	#status["FLspeed"]   = int(i2c.READ(I2C_FLspeed))-100
	#status["FLspdmeas"] = int(i2c.READ(I2C_FLspdmeas))-100
	#status["FRpower"]   = int(i2c.READ(I2C_FRpower))-100
	#status["FRspeed"]   = int(i2c.READ(I2C_FRspeed))-100
	#status["FRspdmeas"] = int(i2c.READ(I2C_FRspdmeas))-100
	#status["BLpower"]   = int(i2c.READ(I2C_BLpower))-100
	#status["BLspeed"]   = int(i2c.READ(I2C_BLspeed))-100
	#status["BLspdmeas"] = int(i2c.READ(I2C_BLspdmeas))-100
	#status["BRpower"]   = int(i2c.READ(I2C_BRpower))-100
	#status["BRspeed"]   = int(i2c.READ(I2C_BRspeed))-100
	#status["BRspdmeas"] = int(i2c.READ(I2C_BRspdmeas))-100
	#MoveMode = int(i2c.READ(I2C_MoveMode))
	#if MoveMode == MoveMode_Speed:
	#	status["MoveMode"] = "Speed"
	#elif MoveMode == MoveMode_Torque:
	#	status["MoveMode"] = "Torque"
	return status
	
	

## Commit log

2014-08-20 license stuff
    [Chassis.fcstd, maehwerktreiber.kicad_pcb, maehwerktreiber.sch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]
2014-09-08 Added documentation/brainstorming and started on ultrasonic position prototyping
    [Battery internals.kicad_pcb, Battery internals.sch, Positioning System.dxf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]
2014-09-13 updated ultrasonic prototype code
    [mowing_plates.dxf, mowing_system_abdeckung.dxf]
2014-09-29 ultrasonic prototype updates
2014-10-08 Added adapter board for CubieBoard 2 (MainModule)
    [EdgeCuts.dxf, MainModule.kicad_pcb, MainModule.sch]
2020-04-10 New Driving Board powered by STM32 Nucleo F401RE
    [driving_module.kicad_pcb, driving_module.sch]
2020-04-10 Micropython based software framework for Driving Module

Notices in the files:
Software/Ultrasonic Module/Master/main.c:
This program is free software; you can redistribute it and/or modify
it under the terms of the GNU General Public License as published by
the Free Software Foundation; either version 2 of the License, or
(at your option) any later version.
